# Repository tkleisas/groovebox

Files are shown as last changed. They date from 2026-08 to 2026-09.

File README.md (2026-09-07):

# groovebox — ВОКОИТЕР / ΟΡΓΑΝΟ

A standalone, battery-powered groovebox: a **Raspberry Pi Zero 2W** brain
running the [yawn](https://github.com/tkleisas/yawn) audio engine, with a
**Raspberry Pi Pico** panel module presenting the whole control surface to
the Pi as a plain USB-MIDI device. Screen, step-sequencer LEDs, encoders,
mic — everything else hangs off those two chips.

Design language: Soviet-cosmonaut mission control per
[bokontep.gr](https://www.bokontep.gr) — deep-red faceplate, cream/black
keys, bilingual Greek/Cyrillic UI strings, terminal-green telemetry.

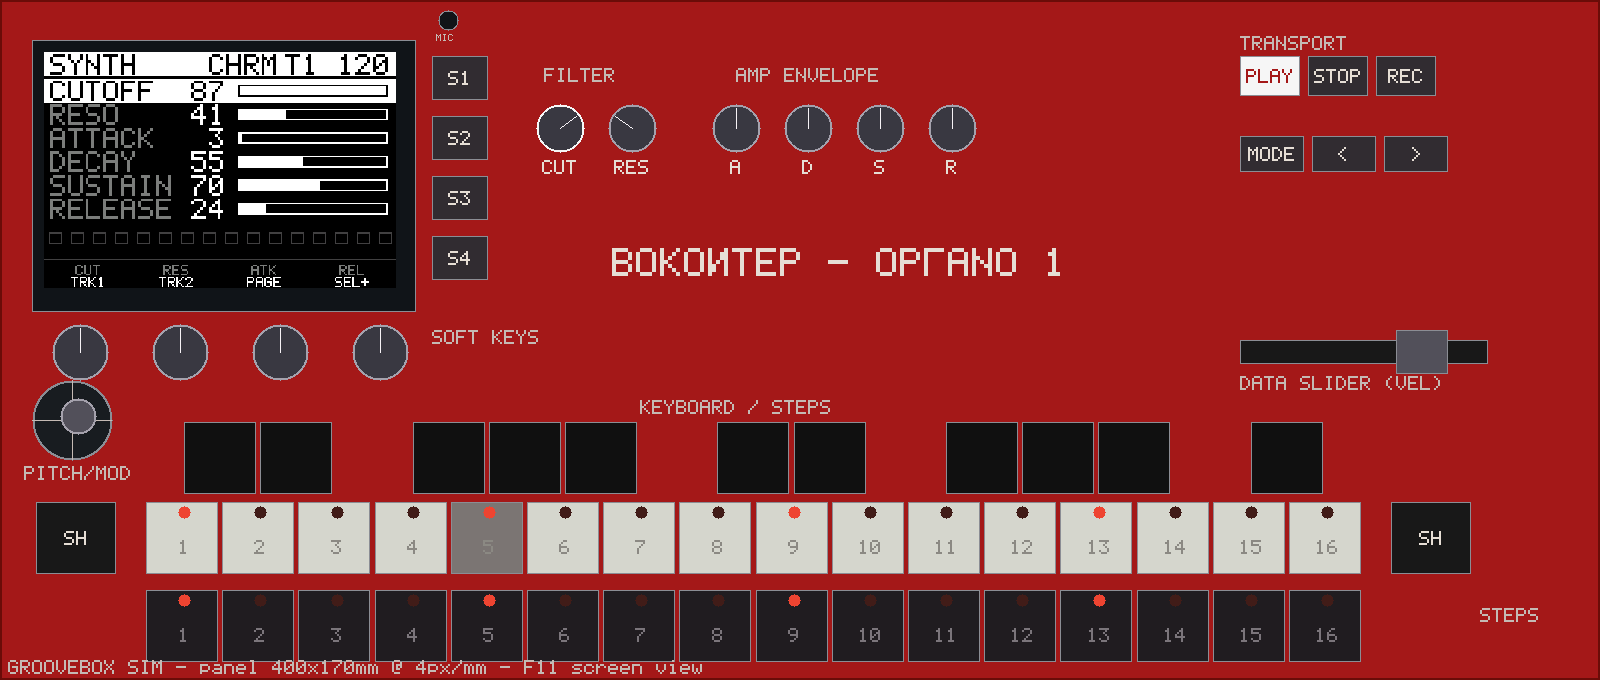
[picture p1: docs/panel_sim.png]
virtual front panel


## Two designs, one repo

| | NSR-1 (ΟΡΓΑΝΟ 1) | NSR-2 |
|---|---|---|
| Concept | full-size panel, 400 × 150 mm | compact, 180 × 210 mm faceplate PCB |
| Keys | 27 MX keys (piano row) + 12 function | 45 Choc keys (4×8 grid) + 13 function |
| Control | 4 encoders, 6 pots, data slider, thumbstick | 4 encoders, thumbstick, crossfader |
| Status | design + hardware spec rev A, KiCad skeletons | schematic-complete, **0 ERC errors**, footprints assigned |
| Docs | [`docs/design.md`](docs/design.md) | [`docs/nsr2-design.md`](docs/nsr2-design.md) + [`nsr2/README.md`](nsr2/README.md) |

## What it does (emulator, today)

- **4 tracks** × **1–256 step patterns** (default 16, 16-step paged window).
  Per-step: on/off, velocity (data slider), accent (black keys), pitch and
  gate (hold-step + encoders, synth track).
- **Play mode**: the keyboard row becomes a 2-octave chromatic keyboard,
  velocity from the slider, joystick = pitch bend / mod. REC-arm + play
  records quantized notes into the pattern. On **drum tracks**
  (DrumSynth/DrumRack/DrumSlop) the 27 keys instead walk the
  instrument's drum voices left→right (whites and interleaved blacks as
  one physical strip, position modulo voice count — wraps at the end,
  so every key always sounds); toasts show the voice name.
- **Sound**: yawn engine instruments (SubtractiveSynth, DrumRack, FM,
  Wavetable, Granular, …) + one insert FX slot per track (29 effect types).
- **Sampling**: SAMPLE page — record from mic/line-in, trim, normalize,
  assign to a drum pad; LOAD page browses samples.
- **Controls (NSR-1)**: 6 dedicated pots (filter cutoff/resonance + amp ADSR
  — strict one-parameter-one-control rule), 4 pageable encoders with push,
  data slider, 2-axis spring-return thumbstick, transport, MODE, </>,
  4 soft keys, dual SHIFT keys at the keyboard row ends.
- **UI**: Elektron-style monochrome, 3 themes (mono / red / green phosphor),
  ПОЕХАЛИ! boot splash, full widget library (sequencer, mixer, waveform,
  ADSR, FM-algo, spectrum, phase pie, tuner, file browser, virtual keyboard…).
- **Sync/IO**: DIN MIDI in/out, Ableton Link (engine), USB-MIDI on OTG,
  integrated mic + line in for sampling (WM8731 codec).

## Hardware (NSR-1, rev A)

| | |
|---|---|
| Brain | Raspberry Pi Zero 2W (≥5 h battery is a hard requirement) |
| Panel controller | Raspberry Pi Pico — presents as USB-MIDI device `groovebox-panel` |
| Audio codec | Audio Injector Zero (WM8731: stereo out + mic/line in). Bench rig: CJMCU-1334 (UDA1334A, playback only) |
| Display | 4.0" SPI TFT 480×320 (ILI9488); UI rendered at 240×160, 2× integer scale |
| Keys | 39 MX-style switches (Gateron Red / Silent Red), hot-swap sockets, per-key LEDs (whites), 19.05 mm pitch |
| Panel I/O | 3× MCP23017 (39 single-ended keys), HT16K33 (16 LEDs), 3× ADS1115 (6 pots + slider + joystick) |
| Power | LiPo + Adafruit PowerBoost 1000C |
| Panel size | 400×150 mm, deep red |

Full hardware design, GPIO maps and BOM: [docs/design.md](docs/design.md).
Panel/brain protocol (USB-MIDI + SysEx config):
[docs/panel-protocol.md](docs/panel-protocol.md).

## Architecture

```
  Pi Zero 2W (brain)                      Pico (panel module)
  ├ yawn engine (I2S codec)      ◄─USB─►  ├ keys    (3× MCP23017)
  ├ fbdev UI → 480×320 SPI TFT            ├ LEDs    (HT16K33)
  ├ DIN MIDI in/out (UART)                ├ encoders (GPIO)
  └ mic (codec input)                     └ analog  (3× ADS1115)
```

The panel is deliberately dumb — it reports physical events and accepts
routing SysEx; **all musical semantics live in the brain app**. The same
app binary runs on the PC (SDL3 emulator with a geometry-driven,
mouse-interactive virtual front panel) and on the Pi (fbdev + panel over
USB-MIDI) through a HAL, which is how everything is developed before
hardware exists. See [`docs/panel-protocol.md`](docs/panel-protocol.md)
for the wire protocol.

## Building

| Target | How | Needs |
|---|---|---|
| Emulator | CMake in `emulator/` (binary `groovebox_sim`) | MSVC or GCC, SDL3, yawn submodule (`git submodule update --init`) |
| Panel firmware | `panel-fw/build.ps1` or CMake with the Pico SDK (see `panel-fw/README.md`) | Pico SDK + toolchain |
| OS image | Raspberry Pi OS Lite + `os-image/customize/` (first-run script, systemd unit) | a Pi / imager |
| Hardware | KiCad 10; NSR-2 schematics are **generated** — see [`nsr2/README.md`](nsr2/README.md) before touching them | KiCad 10.0+ |

Windows/MSVC emulator build:

```bash
CMAKE="/c/Program Files/Microsoft Visual Studio/2022/Community/Common7/IDE/CommonExtensions/Microsoft/CMake/CMake/bin/cmake.exe"
"$CMAKE" -B emulator/build -S emulator -G "Visual Studio 17 2022" -A x64
"$CMAKE" --build emulator/build --target groovebox_sim --config Debug -- -m
emulator/build/Debug/groovebox_sim.exe            # interactive sim
```

The yawn engine is built lean (VST3 / NAM / Link / 3D / ONNX / video OFF).

### Pi cross-build (arm64, Docker)

`tools/build-pi-arm64.sh` builds `groovebox_sim` for 64-bit Raspberry Pi
OS (bookworm, aarch64) in a Docker container — no Pi needed on the desk:

```bash
tools/build-pi-arm64.sh     # image + cross-build + provenance + qemu smoke
```

The image (`emulator/pi/Dockerfile`) is Debian bookworm with the
`aarch64-linux-gnu` toolchain and the **arm64** `libasound2-dev` (ALSA is
the one target-arch dependency — RtMidi and PortAudio are compiled from
source by yawn's FetchContent but link against the target's ALSA). The
toolchain file is `emulator/pi/aarch64-toolchain.cmake`; CMake is driven
with `-DGB_PI_BACKEND=ON`, which swaps the SDL3 SimBackend for the
headless PiBackend (fbdev + RtMidi) and drops the SDL3 link. The script
finishes by proving the binary (`readelf -h` → `AArch64`) and
smoke-running it under `qemu-aarch64` (the container has no ALSA device
PortAudio accepts, so the engine can't boot there — the qemu run proves
execution + graceful peripheral degradation; `--profile` numbers need a
Pi with a codec or the Windows sim).

### Pi backend (PiBackend, `GB_PI_BACKEND=ON`)

- **Display**: fbdev — opens `/dev/fb1` (ILI9488 SPI TFT via fbtft
  overlay), falls back to `/dev/fb0`, mmaps the framebuffer and writes
  the 240×160 RGB565 UI frame 2×-doubled (480×320), centered. 16 bpp
  writes through; 32 bpp (XRGB8888) converts per pixel.
- **Panel in**: RtMidi input on the port named `groovebox-panel`,
  decoded per [`docs/panel-protocol.md`](docs/panel-protocol.md)
  (channel 1: notes 36–91 → keys, CC 20/21 pots, CC 26 slider, CC 1
  joystick Y, CC 16–23 encoder deltas, CC 32–39 encoder push,
  pitch bend → joystick X).
- **LEDs**: note on/off on channel 2 back to the panel.
- Neither peripheral is fatal — a Pi booted without the panel or the
  display logs a warning and keeps the engine running (CI / profiling).
- SIGINT/SIGTERM route to the app's quit path, so the systemd unit or
  Ctrl-C shuts the engine down cleanly.

Deployment note: the arm64 binary dynamically links `libportaudio.so.2`
(yawn builds PortAudio shared). Ship `emulator/build-pi-arm64/lib/libportaudio.so.2`
alongside the binary (e.g. in `/usr/local/lib` + `ldconfig`, or next to
the binary with an rpath). `libasound.so.2` is part of Raspberry Pi OS.

### Heavy-load profiling (`--profile`)

```
groovebox_sim --profile 10
```

Worst-case musical load for the Zero 2W gate: all 4 tracks programmed on
all 16 steps (vel 120), 140 BPM, a reverb inserted on T1+T2, transport
rolling, UI rendering every frame. Prints PortAudio CPU% and the
PortAudio callback status flags (xrun bits) once per second, then exits
0. Runs on every backend (Windows sim, Pi hardware, qemu).

### Interactive controls (sim)

- **Mouse** (panel view): click keys/buttons; drag pots & slider; 2D-drag
  joystick (springs back); wheel over encoders; click encoder = push.
- **PC keyboard**: Z-row + Q-row = piano whites (with standard black-key
  letters/digits), Space = play/stop, Enter = rec, Tab = MODE,
  arrows = </>, F1–F4 = soft keys S1–S4, Shift = SHIFT, F5–F10 + `-`/`=` =
  pots, `[`/`]` = slider, F11 = panel/screen view, F12 = theme, ESC = quit.
- **Track select**: S3/S4 (TRK-/TRK+) or Shift + white keys 1–4;
  Shift + white 5–8 = mute.

### Drum editing (INST page on drum tracks)

For pad instruments (DrumSynth / DrumRack / DrumSlop) the INST page
edits the **last-played pad**: hitting a key in play mode (or a
hold-step voice p-lock) makes that voice the edit pad — the header
shows it (`SNARE T1 140`), an `EDIT SNARE` toast confirms, and all
bindings rebuild to that voice. Sequencer playback never steals the
edit focus.

- **Encoder pages**: PAD / PAD2 = the edited pad's params (DrumSynth:
  Tune/Drive, kick adds Sine/White/Pink; DrumRack: Pad Vol/Pan/Pitch/
  Choke/Start/End; DrumSlop: Pad Vol/Pan/Pitch/Rev/Cutoff/Reso),
  KIT = instrument globals (Volume, OS 2×, slice controls). S2 = PG+
  cycles them.
- **Macro encoders 5–8** (factory binding): A/D = the edited pad's
  attack/decay (S/R also bound on DrumSlop). Pots stay inert on
  DrumSynth/DrumRack (CUT/RES bind only where the instrument exposes
  them — DrumSlop pads).
- DrumSynth has no selected-slot concept — its 36 params are globally
  indexed per voice (kick = 7 @ index 0, others = 4 @ 7+(slot−1)·4),
  so the edit pad is pure index arithmetic; DrumRack/DrumSlop get the
  pad via their `selectedPad` setter.

### Scripted test / asset modes

```
groovebox_sim --smoke       engine boot + notes self-test
groovebox_sim --uitest      UI interaction assertions (8/8)
groovebox_sim --seqtest     sequencer scheduling assertions (6/6)
groovebox_sim --longtest    1–256 step pattern assertions (9/9)
groovebox_sim --paramtest   pot pickup / encoder ownership / FX (11/11)
groovebox_sim --sampletest  mic capture → trim → assign → browser (8/8)
groovebox_sim --panelprobe  synthetic mouse → HAL events (3/3)
groovebox_sim --panel=nsr2 --nsr2test    NSR-2 grid semantics (6/6)
groovebox_sim --revbtest    NSR-1 rev B: step row, p-lock, scale lock (6/6)
groovebox_sim --macrotest   macro encoder assign/bind/reset/persist (6/6)
groovebox_sim --tracktest   engine tracks, INST swap, MFX, type toggle (4/4)
groovebox_sim --bouncetest  clip record, bounce, FX slot 2 (7/7)
groovebox_sim --drumtest    drum key map: voices, wrap, p-lock (9/9)
groovebox_sim --padtest     last-played-pad edit focus (8/8)
groovebox_sim --panel=nsr2 --panelprobe  synthetic mouse on NSR-2 (3/3)
groovebox_sim --widgets     widget showcase → docs/widgets.png
groovebox_sim --profile 10  heavy-load profiling: CPU% + xrun flags/s
groovebox_sim --fontchart   font chart → docs/fontchart.png
groovebox_sim --themes      3-theme chart → docs/themes.png
groovebox_sim --paneldump   panel render → docs/panel_sim.png
groovebox_sim --splashdump  boot splash → docs/bootsplash.png
```

`--panel=<nsr1|nsr2>` selects the panel profile (faceplate, key
semantics, LED count) for interactive, test, and dump modes
(`--panel=nsr2 --paneldump panel.png` renders the NSR-2 faceplate).

## Repository layout

| Path | What it is |
|---|---|
| `docs/` | design documents: NSR-1 `design.md`, panel ↔ brain protocol (`panel-protocol.md`), NSR-2 `nsr2-design.md`, mockups & generated charts |
| `emulator/` | the groovebox app + device emulator (`hal.h`, SimBackend = SDL3 desktop, PiBackend = headless Pi fbdev+RtMidi, PanelView, ui, widgets, font5x7, pattern…), `pi/` = arm64 cross-build (Dockerfile + toolchain) |
| `panel-fw/` | Raspberry Pi Pico firmware (TinyUSB USB-MIDI panel controller, protocol v1 + GRV SysEx config) |
| `hardware/` | NSR-1 hardware: netlist spec + KiCad projects (keyboard & control boards) |
| `nsr2/` | the NSR-2 compact variant: netlist spec, generated KiCad schematics, footprint library, enclosure spec, mockup |
| `os-image/` | Raspberry Pi OS Lite customization — boots straight into the app (~10 s to sound) |
| `tools/` | mockup generators (panel, UI), rgb565 conversion |
| `yawn/` | the audio engine (git submodule) |

## Status & roadmap

NSR-2 is the active design: schematics generated and ERC-clean, board
outlines drawn (180 × 210 faceplate with screen window, 100 × 80 brain
carrier), 3D-printed enclosure specified. Next: PCB layout, firmware
`PANEL_NSR2` variant, emulator `--panel=nsr2` profile. NSR-1 remains the
reference for the audio engine bring-up and the panel protocol.

Software milestones (emulator-first):

- **M1 done** — emulator skeleton: engine headless on PC, HAL, sim window,
  font (Latin/Greek/Cyrillic + symbols), 26 widgets.
- **M2 done** — full instrument in the emulator: live step sequencer
  (1–256 steps), play mode, per-step pitch/gate, virtual front panel,
  themes, boot splash, pot pickup, encoder parameter pages, FX page,
  SAMPLE/LOAD/SETTINGS pages, dialogs. M2d adds one engine track per UI
  track (engine-level mutes, per-track FX), INST page (instrument
  picker with full param rebind), MFX page (MIDI-effect slot), TRACK
  page (channel type MIDI/AUDIO + vol/pan/input/monitor), macro
  encoders (assignable, persisted). AUDIO tracks record input into
  looping clips (REC arm + PLAY/STOP); BOUNCE renders a MIDI track's
  pattern offline to a WAV + looping clip on the first AUDIO track.
  FX page has two insert slots per track (shift+S2 switches).
- **M3 done** — Pi software path: headless PiBackend (fbdev 2× display +
  RtMidi panel per `docs/panel-protocol.md`) behind `-DGB_PI_BACKEND=ON`,
  Docker arm64 cross-build (`tools/build-pi-arm64.sh`, ELF64 AArch64
  verified), `--profile N` heavy-load harness (4 tracks dense, 140 BPM,
  reverb ×2, per-second CPU% + xrun flags).
- **M4** — bench rig: codec, panel firmware on real hardware, display.
- **M5** — battery, enclosure, custom PCB if it earns one.

## Conventions

- Commit messages: `area: summary` (`panel-fw:`, `os-image:`, `nsr2:`, `docs:`).
- Generated files are marked as such in their directories — read
  [`nsr2/README.md`](nsr2/README.md) before hand-editing anything in
  `nsr2/hardware/`.
- Per-device credentials never enter the repo (see `os-image/customize/`).
- License: MIT (see [`LICENSE`](LICENSE)). Vendored third-party hardware
  libraries keep their own licenses — see the footprints table in
  [`nsr2/README.md`](nsr2/README.md).

ПОЕХАЛИ!

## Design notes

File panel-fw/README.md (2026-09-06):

# groovebox-panel firmware

Panel module firmware for the groovebox control surface: a Raspberry Pi Pico
scanning 55 single-ended keys plus 8 encoder pushes on 4x MCP23017 expanders,
2x ADS1115 analog inputs (CUT/RES pots, slider, joystick X/Y), 8 encoders
(5-8 = ADSR) and 32 LEDs driven by an HT16K33 (LED driver only,
no key matrix), presenting everything as a stock USB-MIDI device named
`groovebox-panel` — protocol v1 per [docs/panel-protocol.md](../docs/panel-protocol.md)
(keys as Note On/Off ch1, pots/slider/joystick as CC, encoders relative CC,
LEDs and the host velocity register on ch2, GRV SysEx 0x7D configuration).

## Layout

    CMakeLists.txt          build definition (pico-sdk 1.5.x)
    build.ps1               Windows build helper
    src/board_config.h      pins, I2C addresses, expander key maps — PCB-facing constants
    src/main.c              superloop + 1 ms tick
    src/usb_descriptors.c   "groovebox-panel" MIDI device (VID 0x2E8A, PID 0x4720)
    src/midi.c/.h           TX helpers + RX parser (ch2 notes/CC27/SysEx)
    src/keys.c/.h           55 keys + 8 encoder pushes on 4x MCP23017, debounced scan
    src/ads1115.c/.h        2 chips round-robin, ~125 Hz/channel, hysteresis
    src/encoder.c/.h        8x quadrature IRQ (pushes ride the key scan)
    src/leds.c/.h           32-LED RAM mapping (HT16K33 LED driver) + re-assert
    src/config.c/.h         velocity source routing, GRV SysEx, flash persistence

## Building (Windows)

One-time setup (no admin needed, everything user-scoped under
%USERPROFILE%\pico-tools):

    # 1. pico-sdk 1.5.1 with submodules (last 1.x release; there is no 1.5.2 tag)
    git clone --depth 1 --branch 1.5.1 --recurse-submodules `
        --shallow-submodules https://github.com/raspberrypi/pico-sdk `
        "$env:USERPROFILE\pico-tools\pico-sdk"

    # 2. Arm GNU toolchain 13.2.Rel1 (mingw-w64-i686 zip)
    #    -> extract into %USERPROFILE%\pico-tools
    # 3. ninja-win.zip -> extract into %USERPROFILE%\pico-tools\ninja

Then:

    .\build.ps1 -Configure   # first run
    .\build.ps1              # incremental -> build\panel.uf2

Linux/macOS: standard pico-sdk flow — `cmake -B build -G Ninja` with
arm-none-eabi-gcc on PATH; no Python needed (no PIO/WL features used).

## Flashing

Hold BOOTSEL, plug the Pico, drag `build\panel.uf2` onto the RPI-RP2 drive.
SWD (Pico H 3-pin) works too.

## Testing without the Pi

The panel is a plain class-compliant USB-MIDI device: plug it into any PC and
watch events in a MIDI monitor (amidi / MIDI-OX / web MIDI). Key presses emit
Note On ch1 (36 + key index, velocity from the active source); pots emit
CC20/21 (CUT/RES), the slider CC26, joystick CC1/bend; encoders CC16..23
relative (5-8 = ADSR) and CC32..39 push. Drive LEDs: Note On/Off ch2, note
0..31 (0..15 step row, 16..31 white keys). Configuration SysEx:

    set velocity source = fixed 100   F0 7D 47 52 56 01 08 64 F7
    query capabilities                F0 7D 47 52 56 02 F7
    persistence on                    F0 7D 47 52 56 04 01 F7
    factory reset                     F0 7D 47 52 56 7F F7

## Bring-up knobs (hardware-verification points)

- HT16K33 init sequence in `leds.c` (oscillator on 0x21, brightness 0xE0|8,
  display on 0x81): the chip boots in standby — if no LED lights on first
  boot, verify these writes land with an I2C monitor.
- LED RAM mapping in `leds.c` (LED i -> RAM[i & 7] bit (i >> 3)) must match
  the keyboard PCB routing (ROW anode / COM cathode pairing).
- `KEY_CHIPS` maps (board_config.h): MCP23017 pin -> panel key index; route
  the keyboard PCB to match these tables (or update the tables).
- Encoders: if one detent advances two steps per click, flip the qdec table
  orientation in `encoder.c`.

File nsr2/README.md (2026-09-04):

# NSR-2 — Directory Guide & Collaboration Contract

NSR-2 is the compact sibling of NSR-1 (this repo's `docs/design.md` rev A).
Design docs: `docs/nsr2-design.md`, `nsr2/netlist-spec.md`,
`nsr2/enclosure-spec.md`.

## What generates what

| File | Status | Produced by |
|---|---|---|
| `netlist-spec.md` | **SOURCE OF TRUTH** for all circuits | hand-edited (both of us) |
| `tools/gen_schematics.py` | generator | hand-edited (both of us) |
| `hardware/brain/brain.kicad_sch` | **GENERATED — do not hand-edit** | `gen_schematics.py` |
| `hardware/io/io.kicad_sch` | **GENERATED — do not hand-edit** | `gen_schematics.py` |
| `hardware/nsr2.kicad_sym` | **GENERATED — do not hand-edit** (custom HT16K33A symbol) | `gen_schematics.py` |
| `mockup_panel.py` → `panel_mockup_nsr2.png` | generator + output | hand-edited |
| `hardware/*/*.kicad_pcb` | board outlines machine-made; **layout becomes HAND-OWNED the moment layout work starts in KiCad** | — |
| `hardware/*.kicad_prl`, `erc*.json`, `*_sch.pdf/png`, `*_outline.*`, `io_net.net` | disposable artifacts | KiCad / scripts |

## The collaboration contract

1. **The chain of truth is: `netlist-spec.md` → `gen_schematics.py` →
   `.kicad_sch`.** Any circuit change goes: update the spec → update the
   generator → regenerate → re-verify (ERC + netlist + render) → review.
2. **Never hand-edit the generated `.kicad_sch` files** (or
   `nsr2.kicad_sym`) while this contract is active — regeneration wipes
   hand edits. Spot something wrong? Report it; it gets fixed in the
   generator so the fix survives.
3. **The KiCad GUI is for review and measurement only** during this
   phase (ERC, net highlighter, reading values). Saving a session is
   fine — it only writes view settings (`.kicad_prl`).
4. **Freeze procedure**: when the schematic review passes, we record the
   freeze here (date + commit), after which the `.kicad_sch` files are
   handed over — hand edits in KiCad become the norm, the generator is
   retired for schematics (kept for reference). The `.kicad_pcb` layout
   is hand-owned regardless, from the first moved footprint.
5. Regenerate + verify before every commit that touches hardware.

## Regenerate & verify

```
python nsr2/tools/gen_schematics.py
kicad-cli sch erc  nsr2/hardware/brain/brain.kicad_sch --output out --format json --severity-all
kicad-cli sch erc  nsr2/hardware/io/io.kicad_sch    --output out --format json --severity-all
kicad-cli sch export netlist --format kicadsexpr nsr2/hardware/io/io.kicad_sch --output io_net.net
```

## Known ERC warnings (expected — do not "fix" blindly)

As of the 2026-08-31 generation (with footprints assigned), with
`--severity-all`:

| Board | Count | Class | Meaning |
|---|---|---|---|
| brain | 37 | `lib_symbol_mismatch` | my generated copies differ cosmetically from the installed library defs. **Zero effect** on connectivity, netlist or PCB. Clearable later via *Update Symbols from Libraries*. |
| brain | 1 | `isolated_pin_label` | `MIC_SIG` — intentional: the mic capsule's far end is the codec's physical jack. |
| io | 107 | `lib_symbol_mismatch` | same as above |

**Red flags — these must NEVER appear.** If any of these show up in ERC,
a generation regression happened; stop and diff the generator:

`power_pin_not_driven`, `pin_to_pin`, `label_dangling`,
`pin_not_connected`, `endpoint_off_grid`, `multiple_net_names`,
`footprint_link_issues`.

(Historical note: all of these were real bugs during generation and were
fixed — see `tools/bisect_sch.py` and `tools/exp_power.py`, kept as
regression probes.)

## Footprints

All schematic symbols now carry footprints. The project library
`nsr2_footprints.pretty` (registered in both projects' `fp-lib-table` as
`nsr2_fp`) holds the three that standard KiCad lacks:

| Footprint | Provenance |
|---|---|
| `SW_Hotswap_Kailh_Choc_V1` | [kiswitch library](https://github.com/kiswitch/keyswitch-kicad-library) (CC-BY-4.0), converted to current format |
| `DIN5-RA-PTH` | SparkFun-Connectors.pretty (vendored copy), converted |
| `SW_SPDT_SLIDE_THT` | generated (generic EG1218-class SPDT slide — verify against the bought part) |

Also note: the Pi and Pico sit on **female** headers — their 2×20
symbols use `PinSocket_2x20_P2.54mm_Vertical`, and the screen header is
`PinHeader_1x08_P2.54mm_Horizontal` (right-angle).

## KiCad quick notes for this project

- The schematics use **named labels instead of wires**: every `KEY17`
  label is the same electrical node. Use the net-highlighter (target
  icon, right toolbar) and click a label to see its whole net.
- ERC: *Inspect → Electrical Rules Checker*.
- The custom HT16K33A symbol is embedded, so it displays without extra
  setup; `sym-lib-table` makes the `nsr2` library resolvable for ERC.
- Both boards: io = 180×210 faceplate (screen window at 40,8–140,80),
  brain = 100×80. Outlines are already on Edge.Cuts.

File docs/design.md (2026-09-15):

# Groovebox — Hardware & Software Design

A standalone, battery-powered groovebox built on Raspberry Pi Zero 2W,
using the [yawn](https://github.com/tkleisas/yawn) audio engine as the DSP core.

**Identity: ВОКОИТЕР – ΟΡΓΑΝΟ 1.** Deep-red faceplate (Nord/Elektron red
family), white/black MX keys, near-black shift keys, off-white panel print;
brand badge center-panel in the UI's own multilingual 5×7 font.

Aesthetic direction (per bokontep.gr): Soviet-cosmonaut mission control —
boot splash "ПОЕХАЛИ!", mission-register terminology (project = ΑΠΟΣΤΟΛΗ),
bilingual Greek/Cyrillic UI strings, telemetry-style status pages.
Three screen themes: MONO (white/gray on near-black), RED (bright/light red —
matches the faceplate), GREEN (bright/light green phosphor).

## Core decision

**Pi Zero 2W, fixed by a hard requirement: ≥5 h battery life.**

Considered alternatives:
- Pi 4B: ~3–4× CPU headroom and up to 8 GB RAM, but 3–5 W draw cuts
  battery life to ~2–3 h and it wants a heatsink. Rejected on the battery
  requirement alone.
- CM4: right answer only for a custom carrier PCB / production run.
  Revisit if the box ever goes beyond a one-off.
- Pi 5: power draw and active cooling make it wrong for portable use.

Consequences:
- The core is a swappable module — everything hangs off the standard 40-pin
  header, so a Pi 4B could drop in later with only battery/heatsink changes.
- Milestone 1 must include profiling on the Zero 2W: target workload =
  4 tracks (drum rack + synth + 2–3 FX per track) at 128 frames / 48 kHz.
  Ship criterion: sustained CPU ≤ ~60–65% with no xruns. If it fails, the
  fallback is reducing scope (fewer tracks / lighter FX), not switching
  cores, since battery life is the hard constraint.
- **Measured on real hardware (v0.0.5, snd-dummy, 256 frames, Release):
  lean 4×4-step 120 BPM = 36–43% clean; dense 4×8-step 120 BPM + 1 reverb
  = 55–66% clean; worst-case 16-step 140 BPM + 2 reverbs = ~101% xruns.**
  Verdict: PASSES for the intended envelope. Practical rule: one reverb at
  a time on this core; cheap FX are fine. Re-confirm on the real codec at
  128 frames during bench bring-up (M4).

## Concept

- Mixed sample + synth instrument: yawn's session grid, instruments
  (Sampler, Drum Rack, Subtractive, FM, Wavetable, ...) and effects,
  driven by a physical control surface.
- 4 tracks to start (session-style clip launching), piano-style 16-key step
  row, dedicated filter/ADSR pots, one data slider (default: velocity).
- **Patterns: 1–256 steps, global length, default 16**, grid shows a 16-step
  window (follow-playhead + manual paging via shift+</>). No formal time
  signature — length in steps IS the meter (12 = 3/4, 14 = 7/8); the clock
  counts 16-step bars. Per-step: on/off, velocity (slider at entry),
  accent (black keys), pitch + gate (hold-step + encoders, synth track).
- No desktop OS involvement: Raspberry Pi OS Lite, systemd unit boots
  straight into the app (~10 s boot-to-sound).

## Bill of materials (~$70–80)

| Part | Choice | ~Cost |
|---|---|---|
| Brain | Raspberry Pi Zero 2W | $15 |
| Panel controller | Raspberry Pi Pico (RP2040) — USB-MIDI bridge for all panel I/O | $5 |
| Audio codec (final) | Audio Injector Zero (WM8731: stereo out + mic/line in, stacks on header) | $18 |
| Audio out (bench rig) | CJMCU-1334 = **UDA1334A** I2S DAC, already on hand + proven wiring (`hifiberry-dac` overlay). Playback only — no ADC | $0 |
| Mic | Electret capsule behind top-panel hole → codec mic input | $2 |
| Display | 4.0" SPI TFT 480×320 (ILI9488) — bigger pixels for eyesight; same driver, bus and 240×160@2× UI as 3.5" | $18 |
| MX keyboard kit | 55 MX-style switches (Gateron Red / Silent Red, linear ~45 gf) + Kailh hot-swap sockets + keycap set (16 white, 11 black, 16 step row, colored function keys) | $65 |
| Button/LED driver | HT16K33 (I2C, drives 32 LEDs: 16 step row + 16 white keys) | $3 |
| Key input expanders | 4× MCP23017 (I2C @ 0x20–0x23, 55 single-ended key inputs) | $8 |
| Analog inputs | 3× ADS1115 16-bit ADC (I2C, addresses 0x48 / 0x49 / 0x4a) | $9 |
| Pitch/mod | 2-axis spring-return thumbstick (X = pitch bend, Y = mod) | $4 |
| Pots | 6× 10k linear: cutoff, resonance, A, D, S, R | $7 |
| Data slider | 60 mm slide pot (velocity default; live filter/FX sweeps) | $3 |
| Encoders | 4× rotary encoder with push | $5 |
| DIN MIDI | 2× 5-pin DIN sockets (in+out), 6N138 optocoupler, resistors | $5 |
| Power | LiPo 2000–3000 mAh + Adafruit PowerBoost 1000C | $20 |
| Misc | Power switch, perfboard, headers, enclosure | $5 |

## Control surface

- **Dedicated step row (rev B)**: 16 MX switches *under* the keyboard, one
  per step of the current 16-step window, each with an LED. The step row is
  always the sequencer; the piano row is always playable — no mode split.
  Gestures: tap step = toggle; **hold step + tap piano key = set that
  step's pitch** (p-lock); hold step + encoder = gate; shift+step = accent;
  shift+step on tracks 1–4 area = track select/mute.
- Piano row: 16 white + 11 offset black keys in piano pattern,
  **MX-style switches at 19.05 mm pitch** (Gateron Red / Silent Red, linear
  ~45 gf) in **hot-swap sockets**, per-key LEDs (whites show held notes /
  scale guides), always playable — 2-octave chromatic from C4, velocity
  from the slider. MODE toggles keyboard scale-lock (chromatic ↔ scale).
  External keybeds via DIN MIDI in (USB-MIDI on OTG also possible).
- Transport: play, stop, rec.
- **Two SHIFT keys** (1u MX keys), same logical modifier, at the two ends of
  the keyboard row — thumb/pinky pins shift while the other fingers hit the
  target, so every shift combo is a one-hand move:
  - shift + step row → accent / track select / mute
  - shift + encoder → fine adjust / reset to default
- **MODE** key: toggles keyboard scale-lock (chromatic ↔ scale-locked);
  the sequencer and keyboard are always both live — no mode split.
- **< / >** keys: previous/next event, page, or preset.
- **4 soft menu keys** under the screen: functions shown as on-screen
  labels directly above each key (MPC-style menus, no legend needed).
- 4 encoders with push (pageable parameters).
- **8 encoders total (rev B2)**: 4 pageable + 4 dedicated amp-ENV
  A/D/S/R (relative control — no pickup; envelope follows the track).
  Encoder push-buttons live on spare MCP23017 inputs (quadrature stays on
  16 direct GPIO).
- 2 pots: filter cutoff + resonance (absolute performance controls).
- 1 data slider (velocity entry; mappable).
- 2-axis spring-return thumbstick left of the keyboard: X = pitch bend
  (centers on release), Y = mod, assignable (vibrato / filter / FX depth).
- LEDs mirror pattern + playhead even when the screen shows another page.

Front-panel layout: `docs/panel_mockup.png` (to scale, **400×170 mm panel** —
desktop-instrument class, Push 2 width; regenerate with
`python tools/mockup_panel.py`). Screen-centric design: screen top-left with
the 4 soft menu keys in a column beside it (menu labels drawn on screen next
to each key) and the 4 encoders in a row directly beneath it (parameter
labels + values on screen above each encoder). CUT/RES/A/D/S/R pots
top-middle, transport + MODE/</> cluster top-right, pitch/mod thumbstick
bottom-left, full-width MX piano keyboard (16 white @ 19.05 mm + 11 offset
black, always playable) above a **dedicated 16-key step row** (always the
sequencer, per-step LEDs), 1u SHIFT keys at the piano row ends, horizontal
60 mm data slider above the keyboard's right end. The center holds the
ВОКОИТЕР – ΟΡΓΑΝΟ 1 badge.

## GPIO / I2C allocation

**Pi Zero 2W (40-pin header)** — Pi keeps only display, codec, and DIN MIDI:

| Bus | Pins | Device |
|---|---|---|
| I2S | GPIO 18 (BCK), 19 (LRCK), 21 (DOUT), 20 (DIN) | WM8731 codec (Audio Injector Zero: playback + mic capture) |
| SPI0 | GPIO 8 (CE0), 10 (MOSI), 11 (SCLK) + DC/RST/BL on GPIO 24/25/27 | ILI9488 display |
| I2C1 | GPIO 2 (SDA), 3 (SCL) | WM8731 ctrl @ 0x1a |
| UART | GPIO 14 (TXD), 15 (RXD) | **DIN MIDI out / in** (31250 baud) |
| USB OTG | micro-USB "USB" port | **Panel module (Pico, USB-MIDI device)** |

**Pico (panel module)** — everything else moves here:

| Peripheral | Connection | Role |
|---|---|---|
| HT16K33 | I2C @ 0x70 | 32 LEDs: 16 step-row + 16 white-key (driver only) |
| 4× MCP23017 | I2C @ 0x20 / 0x21 / 0x22 / 0x23 | 55 keys + 8 encoder push-buttons, single-ended (64 available: 63 used) |
| 2× ADS1115 | I2C @ 0x48 / 0x49 | 5 analog inputs: 2 pots (CUT/RES) + slider + joystick (X/Y) |
| 8 encoders | direct GPIO (16 pins, quadrature A/B only) | encoders 1–4 pageable, 5–8 = ADSR |

Notes:
- All 55 keys (16 white + 11 black piano + **16 step row (rev B)** +
  3 transport + 4 soft + MODE + < + > + 2 SHIFT) are **single-ended inputs
  on four MCP23017 I²C expanders** — one uniform scan path, no matrix and
  no per-key diodes (rev A deviation from the original HT16K33-matrix plan:
  the function keys are physically distributed across the panel, and
  expanders keep the board-to-board link at 4 wires with every key
  identical in hardware and firmware). The HT16K33 is solely an LED driver:
  16 step-row LEDs + 16 white-key LEDs.
- Integrated mic: electret capsule wired to the WM8731 mic input (codec bias
  + PGA gain via ALSA mixer). Uses the codec's capture path, no extra bus or
  pins. The WM8731 runs in master mode off an onboard crystal since the Pi's
  I2S has no MCLK output; the stock `audioinjector-wm8731-audio` overlay
  drives it (probes WM8731 at I2C 0x1a).
- Prototyping uses the on-hand CJMCU-1334 (**UDA1334A**, playback-only DAC,
  `hifiberry-dac` overlay — the same recipe as the 2019 intsynth card).
  The mic path arrives with the Audio Injector Zero; UDA1334A + separate
  I2S mic was rejected (custom overlay work, two boards instead of one).
- **DIN MIDI in/out is a core feature.** MIDI out is a TX pin + resistor
  network; MIDI in needs the 6N138 optocoupler (never feed a bare UART).
- On the Zero 2W the PL011 UART is claimed by Bluetooth by default — remap
  it back to GPIO 14/15 via the `pi3-disable-bt` (or `miniuart-bt`) device
  tree overlay, and disable the serial console.
- Software: `ttymidi` bridges `/dev/ttyAMA0` into the ALSA sequencer, so
  yawn's existing RtMidi stack sees DIN MIDI as just another MIDI port —
  clock sync in/out, note in, and MIDI Learn all come along for free.

## Software architecture

**Device emulator first.** All groovebox software is developed against a
hardware abstraction layer (HAL) so the same app binary runs on the PC
(sim backend: SDL3 window showing the exact 240×160 framebuffer at 2×,
keyboard/mouse standing in for keys/encoders/pots) and on the Pi
(fbdev SPI display + **panel module over USB-MIDI**). The PC emulator links the
real yawn engine natively (PortAudio/WASAPI) — UI, page flow, controller
mapping and sequencer logic are all proven before hardware exists.
Milestones: M1 emulator skeleton + headless yawn on PC → M2 full UI +
controller mapping in emulator → M3 cross-compile to Pi, Pi HAL backend,
CPU profiling (Zero 2W viability gate) → M4 bench rig → M5 battery +
enclosure.

**Panel module (Raspberry Pi Pico).** All panel I/O — 39 single-ended keys
on 3× MCP23017, 16 in-switch LEDs on HT16K33 (driver only), 4 encoders,
3× ADS1115 analog — is handled by a Pico (RP2040, native USB device via
TinyUSB) which presents itself to the Pi as a **USB-MIDI controller**. Keys
→ note on/off, pots/slider/joystick → CCs, encoders → relative CCs; LEDs
are driven by MIDI back to the panel; a SysEx layer (protocol doc)
configures velocity-source routing with capability handshake and optional
flash persistence. The Pico is I2C bus master for all expanders (its 26
GPIO can't absorb keys + LEDs + encoders directly). Benefits: no custom
I/O drivers on the Pi (yawn's RtMidi sees a stock USB-MIDI device),
jitter-free scanning, and a panel that is independently testable on any
MIDI host (PC/DAW) and swappable as a unit. The Pi's USB-OTG port goes to
the panel; external keyboards use DIN MIDI in. Firmware: `panel-fw/`
(builds to `panel.uf2` via pico-sdk; see `panel-fw/README.md`).

```
┌─ Input thread (libgpiod: encoders | HT16K33: buttons | ADS1115×2: pots/slider)
│        │  translates to CC / note / shift-layer events
│        ▼
│  "GROOVEBOX" controller backend ──► yawn engine
│        │  (PortAudio/ALSA, 64–128 frame buffer @ 48 kHz,
│        │   existing instruments / FX / session grid,
│        │   Lua 5.4 controller script)
│        ▼  state out: params, playhead, meters, LED state
├─ LED update (HT16K33)
└─ fbdev UI thread → ILI9488, ~15–20 fps, partial redraws
   (C++ + stb_truetype; no GPU — see constraints below)
```

Constraints / decisions:
- yawn's fw2 UI (SDL3 + OpenGL 3.3) cannot run on the Zero 2W
  (VideoCore IV = GL 2.1 / GLES 2.0 at best — fw2's shaders won't compile,
  regardless of the scanout path). The groovebox UI is a new, minimal
  software renderer writing to the Linux framebuffer (fbdev/`fb_ili9488`).
  GPU rendering (GLES2 → FBO → glReadPixels → SPI copy) remains an option
  for future shader-based visualizers (oscilloscope/spectrum), not for
  the core UI.
- **UI style: Elektron-inspired, blocky, near-monochrome** (mockup:
  `docs/ui_mockup.png`, regenerate with `python tools/mockup_ui.py`).
  Rendered at an effective 240×160 and integer-doubled to the display's
  native 480×320 during the SPI blit — 4× less raster work, large glyphs.
  Design language: inverted header bar (page title + context), parameter
  rows (dim name / bright value / thin bar), inverse-video selection
  cursor, footer strip showing the 4 encoders' current assignments,
  white/gray on near-black with at most one accent color (rec-arm,
  playhead, clip state). Partial-row updates to save SPI bandwidth.
- **Widget library** (`emulator/src/widgets.h`, 26 widgets): PhasePie,
  Waveform, Slice, ADSR, FM-algo, Spectrum, Sequencer, StepLane, Mixer,
  Wavetable, Knob, Switch, Radio, VirtualKeyboard, EditBox, FileBrowser,
  List, Toast, TransportClock, NumericField, Dialog, Battery, StatusIcons,
  Tuner, PadGrid, TabBar — all monochrome and data-driven.
  **Grid rule: every widget bbox is a multiple of 8 px (placement prefers
  16 px)** — 240×160 = 30×20 cells; widgets tile without pixel negotiation.
  Showcase: `docs/widgets.png` (regenerate with `groovebox_sim --widgets`).
- 512 MB RAM: ONNX / Demucs / Neural-Amp / video features stay OFF for this
  target (existing CMake feature flags).
- Rootfs mostly read-only + a shutdown button so battery pulls can't
  corrupt the SD card.

## Milestones

1. **Engine on the Pi** — headless yawn build (heavy features off), driven by
   a Lua script, audio out via PCM5102A. De-risks everything; pure software.
2. **Bench rig** — breadboard: encoders, a few buttons, display;
   input → controller backend → engine loop working.
3. **fbdev UI** on the 480×320.
4. **Full control surface** — HT16K33 buttons/LEDs, ADS1115 pots/slider.
5. **Battery + enclosure**, custom PCB if more than one unit is wanted.

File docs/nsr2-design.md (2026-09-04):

# NSR-2 — Compact Panel Variant

NSR-2 is the compact sibling of NSR-1 (this repo's `design.md` rev A).
Same architecture: Pi Zero 2W brain + Pico panel module as a USB-MIDI
device, yawn engine, same panel↔brain protocol v1. The panel is rebuilt
around a 4×8 Choc grid instead of the MX piano row; the pots are dropped
(the 4 encoders cover parameter editing). **Software is nearly
identical**: same app binary, same firmware skeleton, one build-flag
panel variant per hardware.

## Locked decisions

- **Switches**: Kailh Choc low-profile, ~14 mm pitch, hot-swap. MX
  requirement dropped.
- **Grid LEDs**: all 32 keys lit (HT16K33), pattern + playhead mirror as
  in NSR-1.
- **Pitch/mod thumbstick**: stays, on ADS1115 as in NSR-1.
- **Crossfader**: stays (the NSR-1 data slider, repurposed/mix duty).
- **Pots**: CUT/RES/A/D/S/R dropped — 4 pageable encoders take over.
- **Spacebar**: the space key of the quasi-keyboard — the 4×8 grid
  doubles as a text-entry keyboard (project/pattern naming); the wide
  bar types space. Semantics live in the brain (EditBox widget).
  Built as one Choc switch under a wide ~3u (~42 mm) low-profile cap.
- **Layout, top to bottom**: mic hole → screen → 4 soft keys (equally
  spaced under screen) → 4 encoders → transport + < / > on one line →
  4×8 grid → SHIFT-L, spacebar, SHIFT-R.

## Concept sketch

    ┌────────────────────────────────────────┐
    │                 (mic)                  │
    │   ┌──────────────────────────────┐     │
    │   │        480×320 SPI TFT       │     │
    │   └──────────────────────────────┘     │
    │    [S1]      [S2]      [S3]    [S4]    │
    │    (E1)      (E2)      (E3)    (E4)    │
    │  [PLAY] [STOP] [REC] [MODE] [<] [>]   │
    │                                        │
    │       [ ■  ■  ■  ■  ■  ■  ■  ■ ]       │
    │ (J)   [ ■  ■  ■  ■  ■  ■  ■  ■ ]  [F] │
    │       [ ■  ■  ■  ■  ■  ■  ■  ■ ]  [F] │
    │       [ ■  ■  ■  ■  ■  ■  ■  ■ ]       │
    │   [SHIFT]  [━━━━━ space ━━━━━] [SHIFT] │
    └────────────────────────────────────────┘

(J) = pitch/mod thumbstick — left of the grid, vertically centered on
the grid rows (synth pitch-wheel position). (F) = crossfader —
vertical, right of the grid, same centerline: a two-thumb performance
strip flanking the grid. Default mapping is top = A, bottom = B; any
other macro assignment stays brain-side.

## Hardware deltas vs NSR-1 rev A

Architecture unchanged: `Pi ──USB(OTG)── [Pico] ──I²C── peripherals`,
Pico stays bus master at 400 kHz on GP4/GP5. **Pico pin map is reused
verbatim** (encoders GP0–3/6–9 A/B, GP10–13 pushes; GP16/17 UART header
for rev B).

### I²C map (one bus, 400 kHz)

| Addr | Device | Count | Role |
|---|---|---|---|
| 0x20 | MCP23017 | 1 | grid keys 0–15 (rows 1–2: GPA0–7, GPB0–7) |
| 0x21 | MCP23017 | 1 | grid keys 16–31 (rows 3–4: GPA0–7, GPB0–7) |
| 0x22 | MCP23017 | 1 | function keys (13 inputs, 3 spare) |
| 0x48 | ADS1115 | 1 | AIN0 = thumbstick X (bend), AIN1 = Y (mod), AIN2 = crossfader, AIN3 → GND |
| 0x70 | HT16K33A | 1 | 32 grid LEDs, driver only |

Three expanders, same count as NSR-1 — the MCP23017 has 16 I/O pins, so
45 keys need all 48. One ADS1115 instead of three. Bring-up I²C scan
must list exactly: `0x20 0x21 0x22 0x48 0x70`.

### Key budget — 45 inputs

| Index | Note | Key |
|---|---|---|
| 0–31 | 36–67 | grid, row-major (top-left = 0) |
| 32, 33, 34 | 68, 69, 70 | PLAY, STOP, REC |
| 35 | 71 | MODE |
| 36, 37 | 72, 73 | < , > |
| 38–41 | 74–77 | soft keys S1–S4 |
| 42, 43 | 78, 79 | SHIFT-L, SHIFT-R |
| 44 | 80 | SPACE |

MCP #3 pin assignment (pins 0–12): PLAY, STOP, REC, MODE, <, >,
S1–S4, SHIFT-L, SHIFT-R, SPACE. All inputs single-ended on expander
pull-ups, active low — no matrix, no diodes, as rev A.

### LEDs

HT16K33A drives 32 LEDs (COM0–3 × ROW0–7), one per grid key, row-major —
same formula as NSR-1 (`leds.c`: LED i → RAM[i & 7] bit (i >> 3)),
just a larger count. **Series resistors 1 kΩ** (not NSR-1's 470 Ω):
32 × ~3 mA ≈ 96 mA worst case keeps the Pico's ~200 mA external budget
safe; 470 Ω at 32 LEDs would not. The A-variant's 28-SOP brings out
COM0–7 only; ROW0–2 double as the I²C address inputs (left floating →
address 0x70, all 8 ROWs stay usable).

### Panel dimensions (Choc at 14 mm pitch)

- Grid block: 8 × 14 = 112 mm wide; 4 rows + shift/space row = 5 × 14
  = 70 mm tall.
- Thumbstick (left margin) and vertical crossfader (right margin)
  flank the grid, both centered on its rows.
- Panel: **180 × 210 mm** (to-scale mockup: `nsr2/panel_mockup_nsr2.png`,
  regenerated by `nsr2/mockup_panel.py`) vs NSR-1's 400 × 150 mm — about
  two-thirds of the area in a portrait slab. Screen stays the 4.0"
  480×320 ILI9488 (same 240×160@2× UI) — decided over the 3.5" for
  eyesight.

## BOM delta vs NSR-1

| Change | Items |
|---|---|
| Removed | 2× ADS1115, 6× 10k pots, MX switch kit (39 switches, hot-swap sockets, keycaps) |
| Changed | MX kit → ~29× Choc switches + Choc hot-swap sockets + low-profile keycap set (incl. 1u ×2 + wide spacebar, translucent for under-socket LEDs); 16 → 32 LEDs, 470 Ω → 1 kΩ; HT16K33 → HT16K33A |
| Kept | Pico, 3× MCP23017, 1× ADS1115, thumbstick, 60 mm slide pot (crossfader), 4× EC11 encoders, mic capsule → codec |

Net: panel electronics land meaningfully below NSR-1's, dominated by
the MX→Choc kit swap. Power switch, LiPo, PowerBoost, display, codec
and Pi side are untouched.

## Firmware plan

One codebase, build-flag panel variant (`PANEL_NSR1` / `PANEL_NSR2`):

| File | Delta |
|---|---|
| `board_config.h` | NSR-2 `KEY_CHIPS` (3 chips, same count as NSR-1 — new maps), LED count 32, 1× ADS1115 channel map, default velocity source |
| `config.c` | power-up velocity source = fixed 0x08 @ 100 (crossfader is mix duty, not velocity); REPLY feature mask gains bit 3 |
| `keys.c` | chip count stays 3 (no logic change) |
| `leds.c` | count 16 → 32, same RAM formula |
| `ads1115.c` | 9 channels → 3, board-driven |
| `encoder.c`, `midi.c`, `config.h` SysEx layer, `main.c`, TinyUSB | unchanged |

## Protocol notes (v1, unchanged mechanics)

- Key → note mapping stays `note = 36 + index`; the NSR-2 index table
  above replaces NSR-1's.
- **CC 26 = crossfader** (the old "data slider" source), CC 1 =
  thumbstick Y, pitch bend = thumbstick X — same numbers as NSR-1.
- REPLY feature mask: bit 3 = "32-grid layout (NSR-2)". A brain gates
  its grid mapping on this bit at the QUERY handshake — **one brain
  binary serves both panels**, which is what makes the software
  "nearly identical" rather than "forked".
- Velocity source codes apply unchanged; NSR-2 defaults to fixed 100
  and the brain may SET_VELOCITY_SOURCE to the crossfader (0x00) or
  host register (0x09) as on NSR-1.

## Brain-side mapping (semantics)

- **Step mode**: 32 grid keys = 2 bars of 16ths, or 4 tracks × 8 steps
  (pageable, as NSR-1's 16-step window logic); shift+grid = track
  select / mute / scene launch as NSR-1.
- **MODE** toggles play ↔ step ↔ text entry — a toggle, not a
  shift-hold, so both hands stay free to play (NSR-1 rule).
- **Play mode**: scale-locked isomorphic layout on the 4×8 grid (NSR-1's
  chromatic piano has no grid equivalent).
- **Text entry**: grid = QWERTY-flavored quasi-keyboard (4×8: QWERTYUI /
  ASDFGHJK / ZXCVBNM␣␣ / punctuation+enter+backspace), spacebar types
  space — feeds the existing EditBox/VirtualKeyboard flow.
- Emulator first, as always: `--panel=nsr2` sim profile rendering the
  4×8 layout, before any PCB exists.

## Resolved design calls

1. **MODE** — 6th key on the transport line (index 35 / note 71).
2. **Crossfader** — vertical at the grid's right edge, centered on the
   grid rows; fits the ~36 mm side margin where a horizontal 60 mm
   fader would force a full-width row and a taller panel.
3. **Thumbstick** — left of the grid, same centerline; synth
   pitch-wheel position, reachable by either hand's thumb, clear of
   the shift/space row.
4. **Screen** — 4.0" (eyesight priority over ~15 mm width saving).
5. **Spacebar** — one Choc switch under a wide (~3u) cap; slight cap
   tilt at the extremes is acceptable for a text-entry key.

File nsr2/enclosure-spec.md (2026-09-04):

# NSR-2 enclosure specification — 3D printed

The faceplate **is** the IO PCB (deep-red soldermask + cream silk), so
the printed parts are only the body: a bottom tray with walls, standoffs
at two levels, and the rear-edge cutouts. Two printed pieces total.

## Construction

- **Tray** (one print): floor + four walls + standoffs. M3 heat-set
  inserts for the IO faceplate lip and the brain-board standoffs.
- **Lid** = IO faceplate PCB, dropped into the tray lip and secured with
  8× M3 (corners + offset mid pairs at x30/x150, matching the board's
  mounting holes).
- No separate top bezel: the PCB edge-to-wall gap is 1.5 mm all around;
  the tray lip overlaps the faceplate edge by 2 mm.

## Dimensions

| | mm |
|---|---|
| IO faceplate (lid) | 180 × 210 × 1.6 |
| Internal floor | 183 × 213 (1.5 mm clearance) |
| Wall thickness | 2.4 (3 perimeters @ 0.8) |
| External W × D | ≈ 188 × 218 |
| External height | ≈ 27–28 |

## Height stack-up (from the floor up)

| Level | Contents | Height |
|---|---|---|
| 0 | floor (1.6) | 1.6 |
| 1 | battery pouch, in side floor pockets (see placement) | ~8–10 |
| 2 | brain board: PCB 1.6 + 2×20 header 8.5 + Pi Zero ~3 + Audio Injector ~3 | ≈ 18 |
| 2 | Pico assembly under the IO top-right: header 8.5 + Pico ≈ 10 | ≈ 10 |
| 2 | EC11 bodies under the encoder row | ≈ 10.5 |
| 2 | Choc sockets + LEDs under the grid zone | ≈ 4.5 |
| 3 | IO faceplate lip | +2 |

Max under-faceplate stack ≈ 18 mm (brain) + clearance → internal ~20 mm
at the lid level → external ≈ 27–28 mm total. The instrument stays a
flat slab — no wedge in rev A (a rear wedge/stand is a print variant,
same tray, taller rear walls).

## Floor placement zones (top view, panel coordinates)

- **Brain board**: x 40–140, y 0–85 — under the screen/soft-key/encoder
  zone, on 18 mm standoffs, screen header facing up into the faceplate
  window.
- **Battery pouch (2000–3000 mAh, ~34 × 60 × 8)**: side floor pocket,
  x 0–32 or x 148–180 strip beside the encoder/transport rows — clear
  of EC11 bodies (which occupy x 34–146 under y ≈ 95–110), the brain
  stack, and the grid sockets (grid zone under-IO is only ~4.5 mm).
- **Pico**: bottom face of the IO board, top-right; its USB cable runs
  ~100 mm internally down to the brain board's USB-A receptacle.
- **Mic capsule**: glued behind the faceplate's ⌀3 mic hole (90, 5.5),
  foam ring, pigtail to brain J5.

## Rear-wall cutouts (y = 0 edge)

| Cutout | Size | For |
|---|---|---|
| DIN-5 MIDI IN + OUT | 2× ⌀16.5, spaced per brain J2/J3 | DIN sockets, flush |
| Power switch | slot 7 × 13 | brain SW1 actuator |
| Charge port | micro-USB slot 8 × 4 | PowerBoost input |
| SD card slot | slot 13 × 3, positioned over the Pi Zero's µSD edge | re-imaging without opening the box |
| BOOTSEL / RUN | ⌀3.5 hole top edge over Pico SW1 | firmware recovery (NSR-1 convention) |

No front or side cutouts — the USB link is internal; line out/in live on
the Audio Injector's rear 3.5 mm jacks, which face the rear wall: add a
double 3.5 mm cutout aligned with the codec jack row (verify Y position
against the actual Audio Injector Zero jack placement at layout time).

## Fastening & print notes

- M3 heat-set inserts (brass): 8× lid lip, 4× brain standoffs.
- Material: **black PETG** (contrast with the red faceplate) or
  `--red-dark` PETG for a monolith — aesthetic call.
- 0.2 mm layers, 3 perimeters, 15% gyroid; standoffs printed solid.
- Tolerances: holes +0.2 mm, slots +0.3 mm, lip fit test piece first.
- Feet: 4× adhesive silicone ⌀10 × 2 (or printed nubs).

## Open items

1. **Audio Injector Zero exact jack positions** — needed before the rear
   3.5 mm cutout is finalized (measure the real board).
2. **PowerBoost orientation** — its micro-USB charge port must align with
   the rear cutout; pick the J6 header rotation at layout time.
3. Wedge/stand variant — deferred (rev A is a flat slab).
4. Speaker? None — headphone/line only, as NSR-1 (battery budget).

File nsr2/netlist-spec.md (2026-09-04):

# NSR-2 netlist specification — rev A

Definitive hardware↔firmware contract for the two NSR-2 boards. Firmware
side lives in `panel-fw/src/board_config.h` (`PANEL_NSR2` variant); any
change here must update that file (and vice versa) in the same commit.

Manufacturing: 2-layer, 1.6 mm, ENIG, **deep-red soldermask** (bokontep
`--red-dark` family) with cream/white silkscreen — on the IO board the
PCB **is the faceplate**: red mask + cream print replace the aluminum
panel. SMD placed by the fab (JLC economic assembly); every
hand-soldered part is THT.

## Architecture

    ┌─ BRAIN board (100×80) ─────────────┐      ┌─ IO board / faceplate (180×210) ──┐
    │ Pi Zero 2W (2×20 female headers)   │      │ Pico (2×20 female, micro-B flush  │
    │  └ Audio Injector Zero stacks on   │ USB  │   top edge) — USB-MIDI panel      │
    │    the Pi's 40-pin header          │ A→µB │  ├ 3× MCP23017   45 keys          │
    │ ILI9488 4.0" SPI (right-angle hdr) │cable │  ├ HT16K33A    32 LEDs           │
    │ 2× DIN-5 MIDI (6N138 in, R out)    │─────►│  ├ 1× ADS1115    3 analog         │
    │ PowerBoost 1000C + LiPo + switch   │      │  ├ 4× EC11 encoders (XH)          │
    │ USB-A receptacle = Pi OTG breakout │      │  └ 45× Choc hot-swap sockets      │
    └────────────────────────────────────┘      └───────────────────────────────────┘

Two boards exactly as proposed: **Brain** (zero + screen + codec + power +
DIN MIDI) and **IO** (pico + buttons + encoders + LEDs + analog). The only
inter-board link is one USB cable (5V / D+ / D− / GND) — the panel stays an
independently testable USB-MIDI device, as in NSR-1.

I²C map (one bus on the IO board, 400 kHz, Pico master):

| Addr | Device | Role |
|---|---|---|
| 0x20 | MCP23017 | grid keys 0–15 (rows 1–2: GPA0–7, GPB0–7) |
| 0x21 | MCP23017 | grid keys 16–31 (rows 3–4: GPA0–7, GPB0–7) |
| 0x22 | MCP23017 | function keys: 13 inputs (GPA0–5, GPA6–7, GPB0–4), 3 spare |
| 0x48 | ADS1115 | AIN0 = thumbstick X (bend), AIN1 = Y (mod), AIN2 = crossfader, AIN3 → GND |
| 0x70 | HT16K33A | 32 LED driver only (28-SOP brings out COM0–7; address on ROW0–2 at POR, left floating = 0x70) |

**Three expanders, as NSR-1** — the MCP23017 has 16 I/O pins, so 45 keys
need 48 expander pins. I²C pull-ups 4.7 kΩ on the IO board only.

Power: PowerBoost 1000C → 5V rail on the brain board feeds the Pi's 5V
pins; the Pi's OTG port powers the IO board (~115 mA worst case: 32 LEDs
at 1 kΩ + Pico + expanders + HT16K33A + ADS). LiPo 2000–3000 mAh on the
PowerBoost's JST, panel/rear power switch THT on the brain board.

---

## Brain board — 100 × 80 mm

M3 holes (3.2 mm) at (5,5) (95,5) (5,75) (95,75). Pi Zero 2W on 2×20
machined female headers (Audio Injector Zero stacks on the Pi's exposed
male header above it — codec, bias and I2S never touch this board).

### Pi net usage

| Pi pin | Net / function |
|---|---|
| 2, 4 | +5V rail from PowerBoost |
| 1, 17 | 3V3 → screen module logic/backlight |
| 6, 9, 14, 20, 25, 30, 34, 39 | GND |
| 8 / 10 (GPIO14/15) | DIN MIDI out / in (31250 baud, `pi3-disable-bt`) |
| 24 (GPIO8 CE0), 19 (GPIO10 MOSI), 23 (GPIO11 SCLK) | screen SPI0 |
| 18 / 22 / 13 (GPIO24/25/27) | screen DC / RST / BL |
| 5 (GPIO3) | optional shutdown button (rootfs read-only, per design.md) |

### Connectors (THT)

| Ref | Type | Pinout |
|---|---|---|
| J1 | USB-A receptacle | Pi OTG breakout: 1=VBUS, 2=D−, 3=D+, 4=GND (+ shell GND) — short A→micro-B cable to the IO board's Pico |
| J2, J3 | DIN-5 ×2 | MIDI OUT (TX + 33 Ω → pin 4/5, 2=GND) · MIDI IN (6N138: 5→RX, 2/3 opto input + 220 Ω/1 kΩ network) |
| J4 | 2×8 right-angle header | ILI9488 module: VCC(3V3), GND, CS, RST, DC, MOSI, SCLK, LED — plugs up to the screen module fixed in the IO faceplate window |
| J5 | XH-2P | electret mic capsule → Audio Injector Zero mic/line-in jack (3.5 mm pigtail), strain relief |
| SW1 | SPDT THT, rear edge | power switch (PowerBoost EN) |
| J6 | 2×5 header | PowerBoost 1000C mount (5V, GND, EN, LiPo± pigtail to its JST) |

The brain board sits **below** the IO faceplate on enclosure standoffs
(≈18 mm level) under the screen/encoder zone. The Pi's microSD slot on
the Zero's underside stays reachable through an enclosure slot — align
it with the rear wall.

### ICs and discretes

| Ref | Part | Notes |
|---|---|---|
| U1 | 6N138 | MIDI-IN optocoupler (never feed a bare UART) |
| U2 | USBLC6-2SC6 | ESD on USB D+/D− at J1 |
| R1–R5 | MIDI network: 33 Ω, 220 Ω, 1 kΩ, 2× 10 kΩ | per MIDI 1.0 electrical spec |
| C1–C3 | 100 nF 0805 | decoupling U1, U2, screen header |

---

## IO board (faceplate) — 180 × 210 mm

M3 holes at (5,5) (175,5) (30,5) (150,5) (5,205) (30,205) (150,205)
(175,205) — corners plus offset mid pairs (x30/x150), keeping every
standoff clear of the screen window, the mic hole and the shift/space
row. Board outline matches `nsr2/panel_mockup_nsr2.png` with one addition:
a **screen window** cut out of Edge.Cuts at (40, 8)–(140, 80) — the
4.0" ILI9488 module mounts to the faceplate with 4× M2 screws over the
window and connects **down** to the brain board's right-angle header
(the brain board rides ~18 mm below on enclosure standoffs). Mic hole
⌀3 mm at (90, 5.5); capsule glues behind it, wired to brain J5.
Placement by face: Choc sockets + LEDs on the **top** face; all ICs,
Pico and connectors on the **bottom** face (clean faceplate top). Pico
bottom-mounted on 2×20 female headers, micro-B flush with the top edge
(short cable to the brain board's USB-A — internal, no external port).

### Pico pin map — identical to NSR-1 rev A (reused verbatim)

| Pico pin | GPIO | Net / function |
|---|---|---|
| 1 / 2 | GP0 / GP1 | ENC1 A / B |
| 4 / 5 | GP2 / GP3 | ENC2 A / B |
| 6 / 7 | GP4 / GP5 | I²C SDA / SCL (bus master) |
| 9 / 10 | GP6 / GP7 | ENC3 A / B |
| 11 / 12 | GP8 / GP9 | ENC4 A / B |
| 14–17 | GP10–13 | ENC1–4 push |
| 19 / 20 | GP14 / GP15 | spare (rev B) |
| 21 / 22 | GP16 / GP17 | UART link header (optional serial transport) |
| 24–27 | GP18–21 | spare (rev B) |
| 30 | RUN | SW1 reset button → GND |
| 36 | 3V3(OUT) | +3V3 rail |
| 3,8,13,18,23,28,38 | — | GND (use ≥ 4) |

### Key expander maps

MCP #1 @0x20 — grid rows 1–2:

| Pins | Keys |
|---|---|
| GPA0–7 | grid 0–7 (row 1, top) |
| GPB0–7 | grid 8–15 (row 2) |

MCP #2 @0x21 — grid rows 3–4:

| Pins | Keys |
|---|---|
| GPA0–7 | grid 16–23 (row 3) |
| GPB0–7 | grid 24–31 (row 4, bottom) |

MCP #3 @0x22 — function keys (A0→VDD, A1/A2→GND):

| Pin | Key | | Pin | Key |
|---|---|---|---|---|
| GPA0 | PLAY (32) | | GPB0 | S3 (40) |
| GPA1 | STOP (33) | | GPB1 | S4 (41) |
| GPA2 | REC (34) | | GPB2 | SH-L (42) |
| GPA3 | MODE (35) | | GPB3 | SH-R (43) |
| GPA4 | < (36) | | GPB4 | SPACE (44) |
| GPA5 | > (37) | | GPB5–7 | spare (test points) |
| GPA6 | S1 (38) | | | |
| GPA7 | S2 (39) | | | |

All 45 keys: **Kailh Choc V1 hot-swap sockets** (CPG151101S11), switch to
GND, expander pull-ups, active low — no matrix, no diodes. Soft/transport
keys are 1u Choc like the grid (one switch type for the whole panel).

### LEDs — documented deviation from the mockup

**Choc switches have no LED slot** (unlike NSR-1's MX). Per-key lighting
is under-socket instead: 32× 0603 LED centered under each grid socket,
glowing through **translucent/clear low-profile caps**. Drive unchanged:
HT16K33A COM0–3 × ROW0–7, LED i → RAM[i & 7] bit (i >> 3), i = grid index
(row-major), **1 kΩ** series (32 × ~3 mA ≈ 96 mA worst case — inside the
Pico's ~200 mA external budget; 470 Ω would not be).

### Connectors (all JST-XH, THT)

| Ref | Type | Pinout |
|---|---|---|
| J1 | XH-4P | thumbstick: 1=GND, 2=3V3, 3=VRx, 4=VRy |
| J2 | XH-3P | crossfader: 1=GND, 2=wiper, 3=3V3 |
| J3–J6 | XH-5P ×4 | encoders 1–4: 1=A, 2=B, 3=C→GND, 4=D→SW, 5=E→GND (tie 5–3) |
| J7 | XH-4P | UART link: 1=3V3, 2=GND, 3=TX(GP16), 4=RX(GP17) |

No USB receptacle on this board — the brain's USB-A cable plugs into the
**Pico's own micro-B connector** (flush with the top edge); VBUS then
appears on Pico header pin 40 and feeds the +5V rail.

### ICs and discretes

| Ref | Part | Notes |
|---|---|---|
| U1 | MCP23017 (SSOP-28) @0x20 | A0–A2→GND; GPA=keys 0–7, GPB=keys 8–15 |
| U2 | MCP23017 (SSOP-28) @0x21 | A0→VDD, A1/A2→GND; GPA=keys 16–23, GPB=keys 24–31 |
| U3 | MCP23017 (SSOP-28) @0x22 | A1→VDD, A0/A2→GND; function keys per table above |
| U4 | HT16K33A (SSOP-28) @0x70 | LED driver only; custom symbol in `nsr2.kicad_sym` (28-SOP has COM0–7 only; ROW0–2 double as address inputs — leave floating for 0x70) |
| U5 | ADS1115 (MSOP-10) @0x48 | ADDR→GND; AIN0=VRx, AIN1=VRy, AIN2=fader, AIN3→GND, RC filtered |
| R1, R2 | 4.7 kΩ 0805 | I²C pull-ups — this board only |
| R-f ×3 | 10 kΩ 0805 | series, wiper → AINx (RC at the ADS1115 side) |
| C-f ×3 | 100 nF 0805 | AINx → GND |
| LED 1–32 | 0603 red | under grid sockets; anode → COM(i>>3), cathode → 1 kΩ → ROW(i&7) |
| R 1–32 | 1 kΩ 0805 | LED series |
| C1–C4 | 100 nF 0805 | decoupling U1–U4 |

Unused ADS1115 input (AIN3) → GND. ADC_VREF (pin 35) NC.

---

## BOM split

- **Fab assembles (SMD):** IO — 3× MCP23017, ADS1115, HT16K33A, 32× 0603
  LED + 32× 1 kΩ, 3× 10 k + RC set, 2× 4.7 k, decoupling; brain — 6N138,
  USBLC6, MIDI R network, decoupling.
- **Hand-solder (THT):** 45× Choc hot-swap sockets, Pico + Pi female
  headers, screen right-angle header, USB-A receptacle, 2×
  DIN-5, all XH connectors, EC11s (panel-wired via XH), PowerBoost,
  power switch, tact (RUN).
- **Modules (bought, not designed):** Pi Zero 2W, Audio Injector Zero,
  ILI9488 4.0" SPI module, Pico, thumbstick, 60 mm slide pot, LiPo +
  PowerBoost 1000C, translucent Choc cap set (incl. 2× 1u + 1× ~3u).

## Schematics

The schematics are **generated**: `nsr2/tools/gen_schematics.py` emits
both `.kicad_sch` files (and the `nsr2.kicad_sym` project library with
the custom HT16K33A symbol) from this spec — rerun it after any change
here, then re-check with `kicad-cli sch erc`. Status: **0 ERC errors**
on both boards; remaining warnings are benign and enumerated in
`nsr2/README.md` (embedded-copy vs library mismatch, the intentional
single-pin MIC label, footprint names to finalize at layout: DIN-5
sockets, power switch, Choc hot-swap sockets). Board outlines
(180×210 faceplate with screen window, 100×80 brain) are already
captured in the `.kicad_pcb` files. See `nsr2/README.md` for the
collaboration contract (what may be hand-edited and when).

## Bring-up checklist

1. IO I²C scan must list exactly: `0x20 0x21 0x22 0x48 0x70`.
2. LEDs: Note On ch2 (note 0–31) — LED i glows under grid key i+1.
3. Keys: every key emits 36 + index (protocol table); ghost-free by
   construction (no matrix).
4. Analog: sweep thumbstick X/Y + crossfader; verify bend, CC 1, CC 26.
5. Encoders: detents → CC 16–19 (65/63); pushes → CC 32–35.
6. GRV SysEx: QUERY/REPLY (feature bit 3 set = NSR-2 layout),
   velocity-source switching, persistence round-trip.
7. Brain: USB-A port enumerates the Pico; MIDI DIN loopback; screen on
   SPI0 at 32 MHz; boot-to-sound with the codec stacked.
8. UART header continuity (GND/3V3/TX/RX) for the future serial transport.

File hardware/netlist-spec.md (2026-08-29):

# Hardware netlist specification — rev A

Definitive hardware↔firmware contract for the two control-surface boards.
Firmware side lives in `panel-fw/src/board_config.h`; any change here must
update that file (and vice versa) in the same commit.

Manufacturing target: 2-layer, 1.6 mm, ENIG, green→**deep-red soldermask**
(faceplate aesthetic), white silkscreen. SMD parts placed by the fab
(PCBWay/JLC economic assembly); every hand-soldered part is THT.

## Architecture

    Pi Zero 2W ──USB(OTG)── [Pico] ──I2C──┬── 3× MCP23017   39 keys, uniform
             (power+MIDI)   │  GP4/GP5    ├── HT16K33      16 step LEDs
                            │             └── 3× ADS1115    9 analog inputs
                            ├─ 4× EC11 encoders (direct GPIO)
                            ├─ RUN button, UART link header (optional serial)
                            └─ micro-USB → Pi OTG port

All 39 keys are **single-ended inputs on MCP23017 expanders** (switch to GND,
expander pull-ups, active low): no matrix, no per-key diodes, one uniform
scan path in firmware. The HT16K33 is a pure LED driver. This supersedes the
design.md rev-0 idea of HT16K33 key scanning (documented deviation).

I²C map (one bus, 400 kHz):

| Addr | Device | Board | Role |
|---|---|---|---|
| 0x20 | MCP23017 | keyboard | white keys 0–15 |
| 0x21 | MCP23017 | keyboard | black keys 16–26, shifts 38/39, 3 spare |
| 0x22 | MCP23017 | control | function keys + joystick SW, 5 spare |
| 0x48 | ADS1115 | control | pots 1–4 |
| 0x49 | ADS1115 | control | pots 5–6, slider, joystick Y |
| 0x4A | ADS1115 | control | joystick X (pitch bend) |
| 0x70 | HT16K33  | keyboard | 16 LED driver only |

Power: Pico is powered from the Pi's OTG port over its own micro-USB;
everything runs from 3V3(OUT) (pin 36). Budget: LEDs 16×6 mA ≈ 96 mA +
4×MCP + 3×ADS + HT16K33 ≈ **~130 mA worst case** — inside the Pico's ~200 mA
external budget. Keep LED resistors ≥ 470 Ω.

---

## Control board — 90 × 70 mm

M3 mounting holes (3.2 mm) at (5,5) (85,5) (5,65) (85,65).
Pico on 2×20 machined female headers (J1A pins 1–20, J1B pins 21–40),
module micro-USB flush with the **bottom edge** (cable to Pi OTG), BOOTSEL
reachable through an enclosure hole.

### Pico pin map

| Pico pin | GPIO | Net / function |
|---|---|---|
| 1 / 2 | GP0 / GP1 | ENC1 A / B |
| 4 / 5 | GP2 / GP3 | ENC2 A / B |
| 6 / 7 | GP4 / GP5 | I²C SDA / SCL (bus master) |
| 9 / 10 | GP6 / GP7 | ENC3 A / B |
| 11 / 12 | GP8 / GP9 | ENC4 A / B |
| 14–17 | GP10–13 | ENC1–4 push |
| 19 / 20 | GP14 / GP15 | spare (rev B) |
| 21 / 22 | GP16 / GP17 | UART link header (optional serial transport) |
| 24–27 | GP18–21 | spare (rev B) |
| 29 | GP22 | spare (rev B) |
| 30 | RUN | SW1 reset button → GND |
| 31–34 | GP26–28 | spare (rev B; ADC-capable) |
| 36 | 3V3(OUT) | +3V3 rail |
| 3,8,13,18,23,28,38 | — | GND (use ≥ 4) |

### Connectors (all JST-XH, THT)

| Ref | Type | Pinout |
|---|---|---|
| J2–J7 | XH-3P ×6 | pots 1–6: 1=GND, 2=wiper, 3=3V3 |
| J8 | XH-3P | data slider: 1=GND, 2=wiper, 3=3V3 |
| J9 | XH-4P | joystick module: 1=GND, 2=3V3, 3=VRx, 4=VRy |
| J10–J13 | XH-5P ×4 | encoders 1–4: 1=A, 2=B, 3=C→GND, 4=D→SW, 5=E→GND (tie 5–3 on board) |
| J14 | XH-4P | keyboard link: 1=3V3, 2=GND, 3=SDA, 4=SCL |
| J15 | XH-4P | UART link: 1=3V3, 2=GND, 3=TX(GP16), 4=RX(GP17) |
| J16–J25 | XH-2P ×10 | function keys: 1=U4 GPIO, 2=GND (PLAY, STOP, REC, MODE, <, >, S1–S4 in that order) |
| J26 | XH-2P | joystick SW |
| J27, J28 | XH-2P | spare inputs (U4 pins 12–15 remain for rev B) |

### ICs and discretes

| Ref | Part | Notes |
|---|---|---|
| U1 | ADS1115 (VSSOP-10) @0x48 | ADDR→GND. AIN0–AIN3 ← pots 1–4 |
| U2 | ADS1115 @0x49 | ADDR→3V3. AIN0←pot5, AIN1←pot6, AIN2←slider, AIN3←VRy |
| U3 | ADS1115 @0x4A | ADDR→SDA. AIN0←VRx; AIN1–3 → GND |
| U4 | MCP23017 (SSOP-28 or SPDIP-28) @0x22 | ADDR strap A1→VDD, A0/A2→GND. All 16 GPA/B inputs (J16–J28) |
| SW1 | 6 mm tact, THT | RUN → GND |
| R-f ×9 | 10 kΩ 0805 | series, wiper → AINx (RC filter, place at the ADS1115 side) |
| C-f ×9 | 100 nF 0805 | AINx → GND |
| R1, R2 | 4.7 kΩ 0805 | I²C pull-ups — **control board only**, never duplicate on keyboard |
| C1–C4 | 100 nF 0805 | decoupling, one per IC |

Unused ADS1115 inputs → GND. ADC_VREF (pin 35) NC.

---

## Keyboard board — 356 × 62 mm

M3 holes at (5,5) (351,5) (5,57) (351,57).
29 MX hot-swap sockets (Kailh, THT): SH-L, 16 whites, 11 blacks, SH-R.
Whites at 19.05 mm pitch; blacks on the upper row (y offset ≈ −22 mm) at the
piano gaps {1,2, 4,5,6, 8,9, 11,12,13} plus one far-right position; shifts at
the row ends. Gateron Red / Silent Red, 3 mm LED slot in whites.

| Ref | Part | Role |
|---|---|---|
| U1 | MCP23017 @0x20 (A0–A2→GND) | GPA/B = white keys 0–15, in white-key order |
| U2 | MCP23017 @0x21 (A0→VDD) | pins 0–10 = blacks 16–26, pins 11/12 = shifts 38/39, 3 spare (test points) |
| U3 | HT16K33 (SOP-28) @0x70 | LED driver only — key-scan RAM unused |
| J1 | XH-4P | I²C link to control board (same pinout as J14) |
| LED 1–16 | 3 mm THT, in switch slots | anode → COM(i>>3), cathode → R 470 Ω → ROW(i&7), i = white key index − 1 |
| R1–R16 | 470 Ω 0805 | LED series |
| C1–C3 | 100 nF 0805 | decoupling U1–U3 |

LED/HT16K33 mapping must stay in lockstep with `panel-fw/src/leds.c`
(LED i → RAM[i & 7] bit (i >> 3)). No I²C pull-ups on this board.

---

## BOM split

- **Fab assembles (SMD):** keyboard — 2× MCP23017 (SPDIP-28 if keeping it
  fully hand-solderable, else SOIC-28), HT16K33, 16× 470 Ω, 3× 100 nF;
  control — 3× ADS1115, MCP23017 (SSOP-28), 9× 10 k + 13× 100 nF, 2× 4.7 k.
- **Hand-solder (THT):** all hot-swap sockets, all XH connectors, Pico
  sockets, tact switch, LEDs, encoder/pot/slider/joystick modules (wired).

## Bring-up checklist

1. I²C scan must list exactly: 0x20 0x21 0x22 0x48 0x49 0x4A 0x70.
2. LEDs: Note On ch2 (note 0–15) — verify LED i maps to white key i+1.
3. Keys: every key emits 36 + index (protocol table); chords ghost-free by
   construction (no matrix).
4. Analog: sweep each pot/slider/joystick; verify CC 20–26, CC 1, bend.
5. Encoders: detents → CC 16–19 (65/63); pushes → CC 32–35.
6. GRV SysEx: QUERY/REPLY, velocity source switching, persistence round-trip.
7. UART header continuity (GND/3V3/TX/RX) for the future serial transport.

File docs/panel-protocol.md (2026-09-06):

# Panel ↔ Brain Protocol (USB-MIDI)

The panel module (Pico) presents as a USB-MIDI device named `groovebox-panel`.
All panel→brain traffic rides this protocol; the brain sends LED state back
on channel 2. The emulator's sim backend emits/consumes the same logical
messages, so app code never cares which side is real.

Channel 1 = panel → brain. Channel 2 = brain → panel (LEDs).

## Panel → brain

### Keys (55 total, rev B)

Every panel key sends Note On (press, velocity = current value of the
configured **velocity source**, 1–127 — slider by default, see
[Panel configuration](#panel-configuration-sysex-id-0x7d)) and Note Off
(release). Note number = 36 + key index.

| Index | Note | Key |
|---|---|---|
| 0–15 | 36–51 | white keys 1–16 (piano row, always playable) |
| 16–26 | 52–62 | black keys, left to right (C♯ pattern order) |
| 27–29 | 63–65 | transport: PLAY, STOP, REC |
| 30 | 66 | joystick push |
| 31 | 67 | MODE (keyboard scale-lock toggle) |
| 32, 33 | 68, 69 | < , > |
| 34–37 | 70–73 | soft keys S1–S4 |
| 38, 39 | 74, 75 | SHIFT-L, SHIFT-R |
| 40–55 | 76–91 | **step row 1–16** (rev B: dedicated sequencer row under the piano) |

Both shifts are logically identical; the brain may merge them.

### Analog (CC, channel 1, 7-bit MSB only for rev A)

| CC | Source |
|---|---|
| 20 | pot CUTOFF |
| 21 | pot RESONANCE |
| 22–25 | ~~pots ATTACK/DECAY/SUSTAIN/RELEASE~~ — removed in rev B2 (ADSR moved to encoders 5–8); reserved |
| 26 | data slider (default velocity source — see Panel configuration) |
| 1  | joystick Y (mod) |
| pitch bend | joystick X (spring-returned, center = 8192) |

### Encoders (relative CC, channel 1)

| CC | Source |
|---|---|
| 16–23 | encoder 1–8 rotation: two's-complement relative (64 = no movement, 65 = +1 detent, 63 = −1 detent). Encoders 5–8 = amp-ENV A/D/S/R (rev B2) |
| 32–39 | encoder 1–8 push: 127 on press, 0 on release |

## Brain → panel (LEDs, channel 2)

Note On/Off on channel 2. Notes 0–15 = **step-row LEDs**, 16–31 =
**white-key LEDs** (NSR-1 rev B). Velocity ignored for rev A (single
intensity); velocities 1–127 may later map to PWM brightness.

CC 27 on channel 2 is the **host velocity register**: the brain writes the
live velocity value (1–127) it wants stamped on subsequent Note Ons while
the velocity source is `host register` (see Panel configuration). All other
channel-2 CCs are reserved.

## Panel configuration (SysEx, ID 0x7D)

Panel routing is host-configurable via vendor SysEx on the free
non-commercial manufacturer ID `0x7D`. Configuration is **routing, not
semantics**: the panel still only reports physical events — the brain merely
chooses which physical value stamps Note On velocity. All musical meaning
stays app-side (final section).

Frame: `F0 7D 47 52 56 <cmd> [args…] F7` — `47 52 56` is ASCII `GRV`.

| Cmd | Name | Args | Effect |
|---|---|---|---|
| 0x01 | SET_VELOCITY_SOURCE | `src` (+ `value` when `src` = 0x08) | velocity source for Note On, captured at the press instant |
| 0x02 | QUERY | — | panel replies with 0x03 (below) |
| 0x03 | REPLY | `proto_ver`, `feature_mask` | panel → brain: protocol version (currently 1) and capability bits |
| 0x04 | SET_PERSISTENCE | `mode` | 0 = volatile (default), 1 = save-on-change |
| 0x7F | RESET_DEFAULTS | — | velocity source = slider, persistence = volatile; erases any saved config |

Velocity source codes for 0x01:

| `src` | Meaning |
|---|---|
| 0x00 | data slider (power-up default — rev A behavior) |
| 0x01–0x02 | pot 0–1: CUTOFF / RESONANCE (the CC 20–21 sources) |
| 0x03–0x06 | legacy rev A pots — clamp to the nearest real pot (rev B2: only two pots exist) |
| 0x07 | joystick Y (the CC 1 source) |
| 0x08 | fixed value, next byte 1–127 |
| 0x09 | host register (CC 27 on channel 2) |

Feature mask bits (REPLY): bit 0 = velocity source assignment, bit 1 =
config persistence, bit 2 = host velocity register. A brain that wants
optional behavior gates on these bits, not on the version byte.

Rules:

- **Volatile by default.** With persistence off, the panel powers up with
  velocity source = slider and no stored config. The brain re-sends its
  configuration after the QUERY handshake at boot and on mode changes.
- **Save-on-change.** With persistence on, each accepted config command is
  written to flash and restored at power-up. The firmware coalesces writes
  (at most one flash write per second of sustained changes) to spare the
  flash; the brain should still avoid high-rate configuration streams.
- **Unknown commands are ignored, never rejected** — a rev B panel may
  accept commands an older brain does not know, and vice versa. QUERY plus
  the feature bits is the discovery mechanism.
- **Unknown `src` codes fall back to the slider**, never to a dead velocity.

## NSR-2 panel variant

NSR-2 is the compact portrait panel (180x210 mm, 4x8 Choc grid — see
`docs/nsr2-design.md`). Same protocol v1 mechanics; different key map,
LED count, and defaults.

### Key map (45 keys, channel 1, note = 36 + index)

| Index | Note | Key |
|---|---|---|
| 0–31 | 36–67 | grid keys, row-major (top-left = 0) |
| 32, 33, 34 | 68, 69, 70 | PLAY, STOP, REC |
| 35 | 71 | MODE |
| 36, 37 | 72, 73 | < , > |
| 38–41 | 74–77 | soft keys S1–S4 |
| 42, 43 | 78, 79 | SHIFT-L, SHIFT-R |
| 44 | 80 | SPACE (wide bar) |

### Differences vs NSR-1

- **No pots, no data slider.** The 60 mm control is a **crossfader** on
  **CC 26** (same channel/index as NSR-1's slider). Thumbstick stays:
  CC 1 (Y / mod) and pitch bend (X), unchanged.
- **32 LEDs** (one per grid key): brain → panel note on/off on channel 2,
  note number = LED index **0–31** (row-major, same formula as NSR-1
  extended to 4x8).
- **Velocity source default = fixed 100** (`src` 0x08 @ 100) — the
  crossfader is mix/performance duty by default; the brain may
  SET_VELOCITY_SOURCE to 0x00 (crossfader) or 0x09 (host register) as
  on NSR-1.
- **REPLY feature mask gains bit 3 = "32-grid layout (NSR-2)"** so one
  brain binary gates its grid mapping on the QUERY handshake.
- MODE cycles three keyboard-row modes: **step → play → text** (NSR-1
  has step ↔ play only). Play mode is a scale-locked isomorphic grid
  (row up = +4 semitones, column = +1, base C3); text mode is a
  QWERTY-flavored grid feeding the EditBox flow.

## Semantics live in the brain

The panel is dumb: it reports physical events, nothing more. Key → musical
note mapping (scale/octave/play-vs-step mode), shift layers, velocity
interpretation (the panel's source binding is mere routing — see Panel
configuration), and all mode logic are app-side. This keeps the panel
firmware stable and the behavior firmware-free.

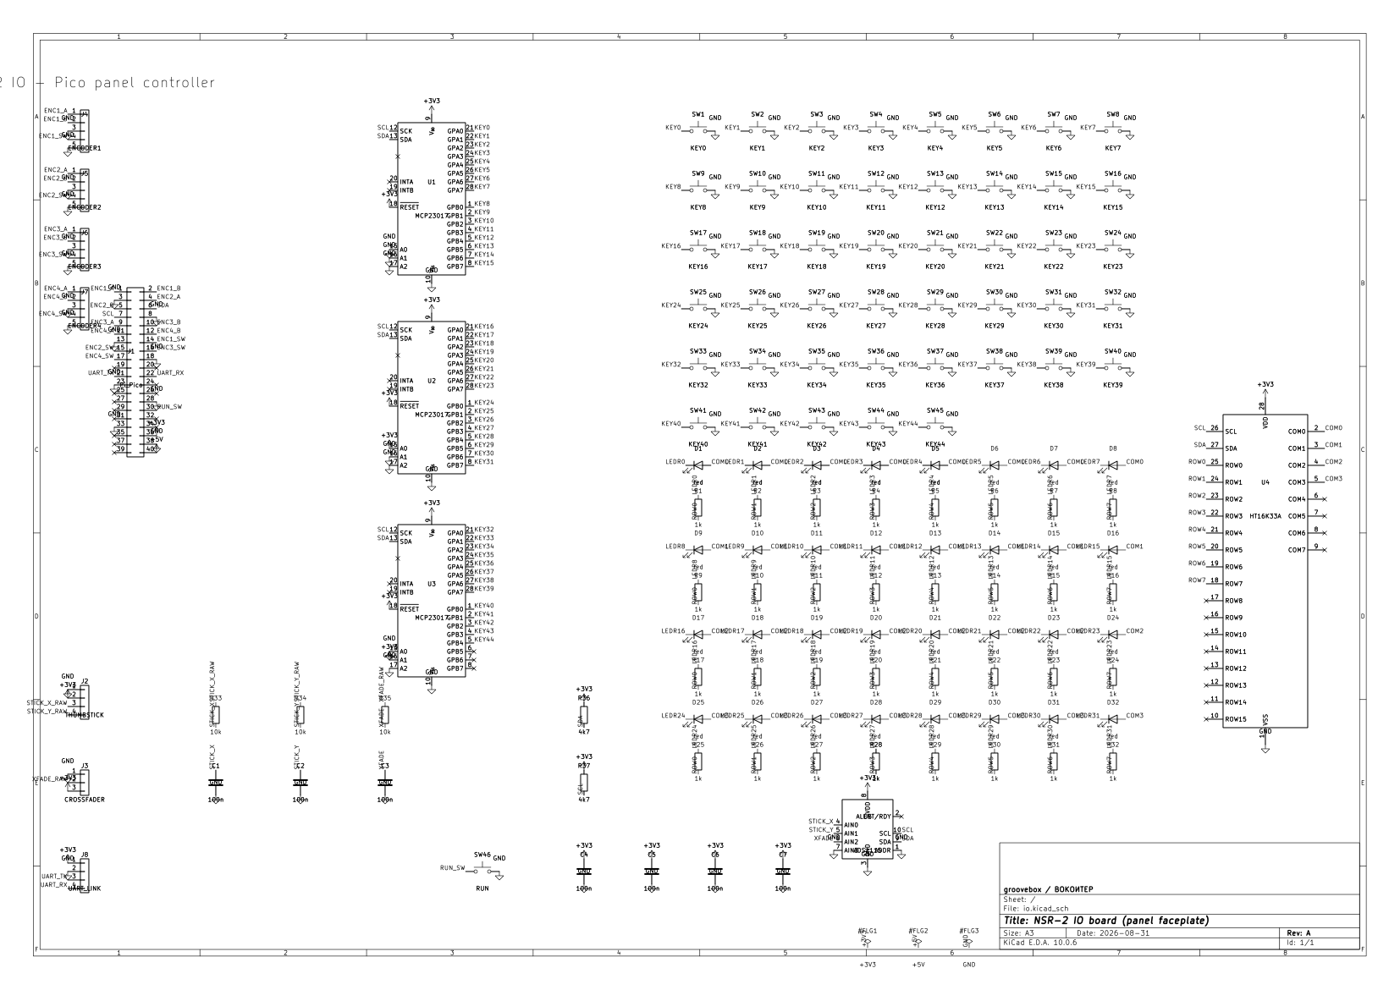
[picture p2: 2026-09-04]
nsr2/hardware/io/io_sch.png

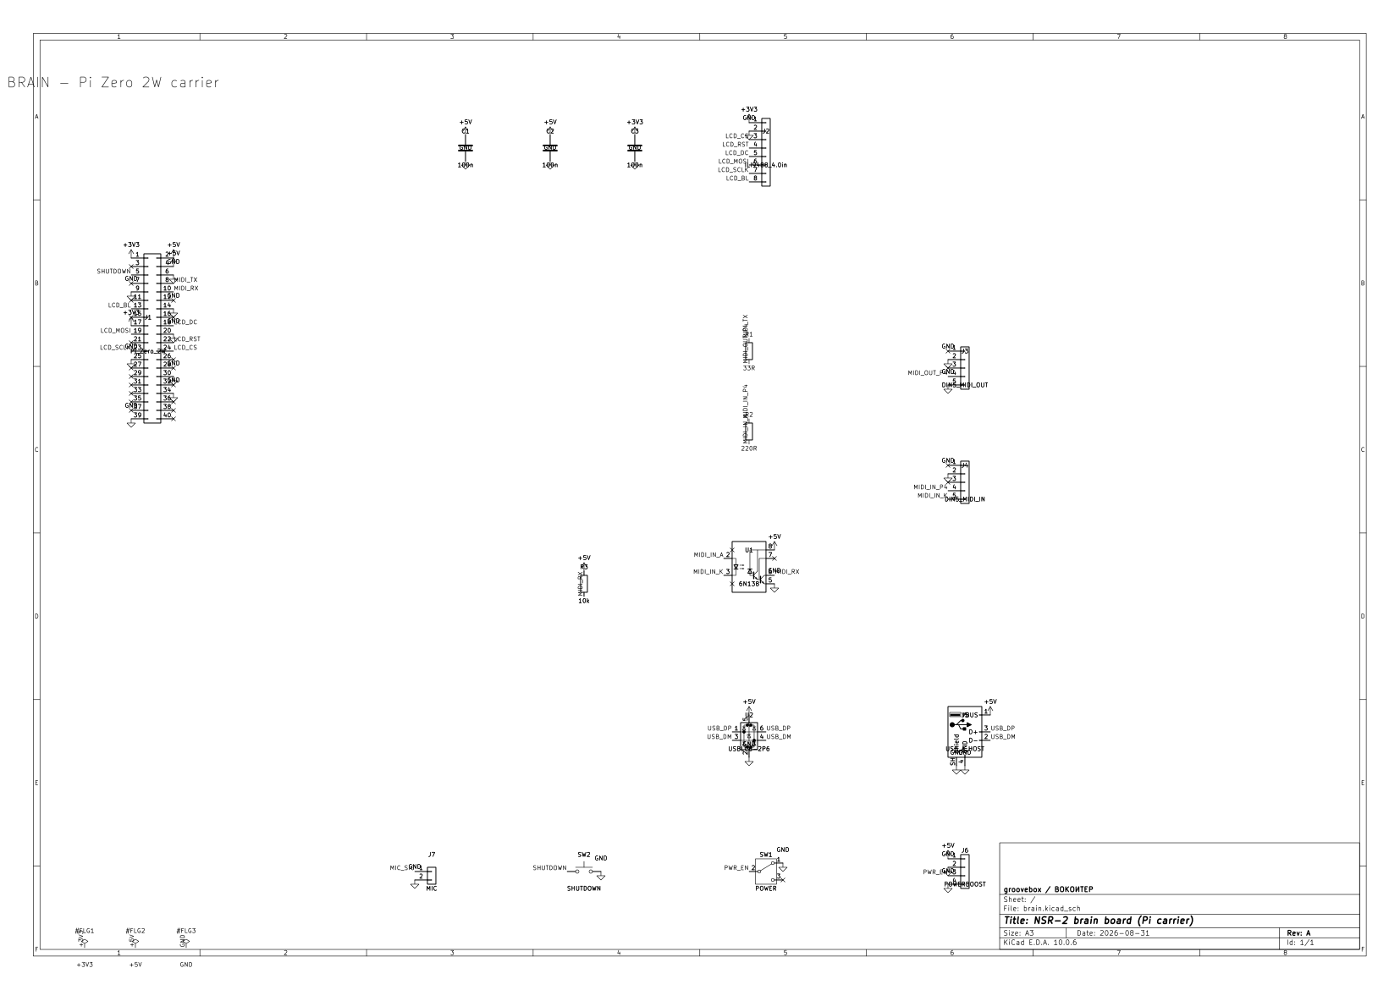
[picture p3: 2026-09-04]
nsr2/hardware/brain/brain_sch.png

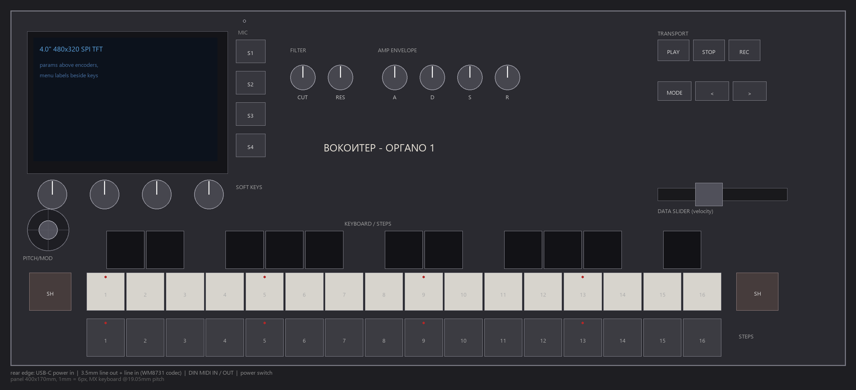
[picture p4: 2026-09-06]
docs/panel_mockup.png

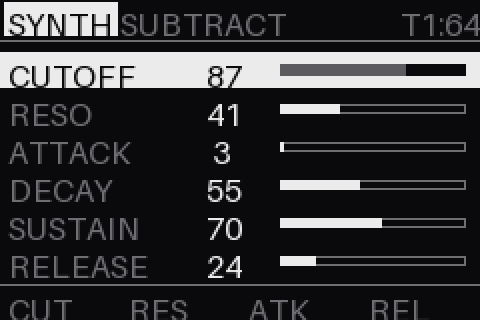
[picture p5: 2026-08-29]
docs/ui_mockup.png

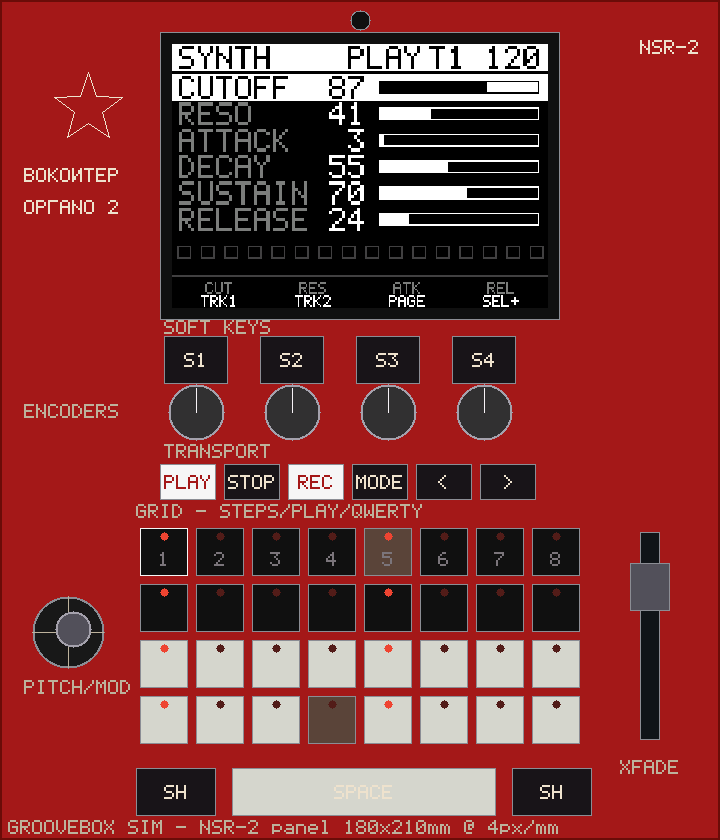
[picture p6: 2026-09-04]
docs/panel_sim_nsr2.png

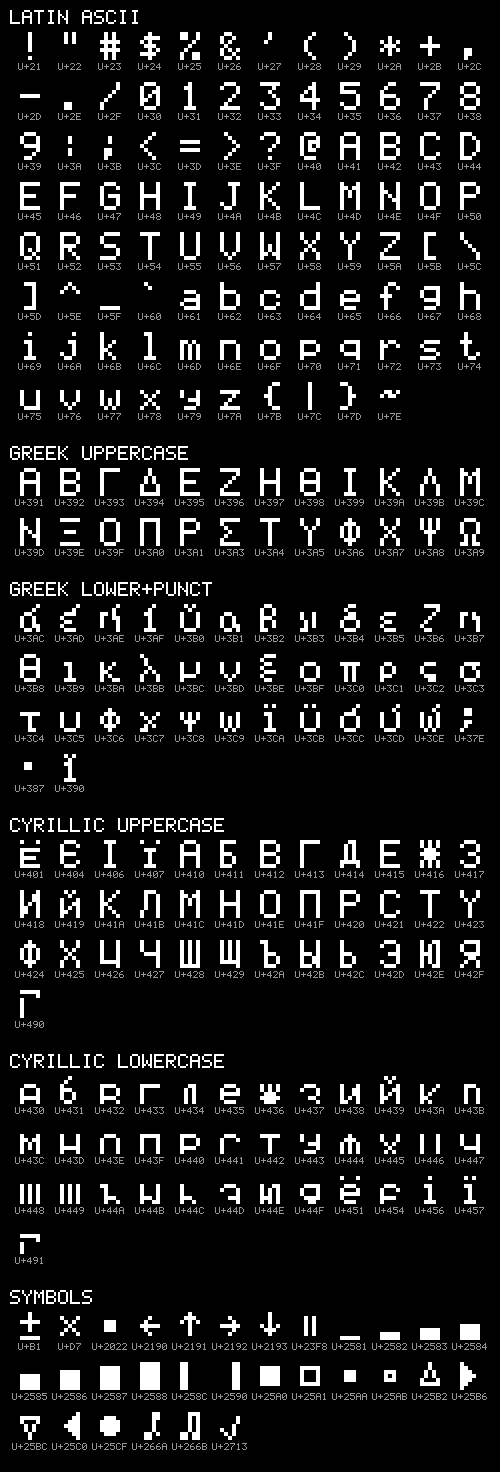
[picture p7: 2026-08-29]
docs/fontchart.png

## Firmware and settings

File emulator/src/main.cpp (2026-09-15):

// groovebox_sim — PC emulator for the groovebox control surface.
//
// Boots the yawn audio engine headlessly (PortAudio default output),
// a SubtractiveSynth on track 0 and a DrumRack on track 1, maps the
// simulated 39-key panel (key indices per docs/panel-protocol.md) to
// engine MIDI commands, and renders Elektron-style UI pages to the
// 240x160 framebuffer shown in an SDL3 window. Engine boot, sequencer
// triggers and note events are logged to stdout so the behavior is
// verifiable without listening.
//
// Tracks: T1 = SubtractiveSynth (melodic), T2/T3/T4 = DrumRack lanes
// (kick 36 / hat 38 / clap 39), all pattern-driven by the 16-step
// sequencer while the transport runs.
//
// Usage: groovebox_sim [--smoke|--seqtest|--uitest]
//                      [--fontchart [out.png]] [--widgets [out.png]]
//   --smoke     unattended boot + notes on both engine tracks + one
//               frame dump per page, clean shutdown.
//   --seqtest   unattended sequencer test: programs steps, plays at
//               120 BPM, changes BPM mid-play, mutes T3, records a
//               note, asserts trigger counts, dumps SEQ frames.
//   --uitest    unattended interaction test: hold-step pitch editing,
//               TRK+/TRK- wrap, shift-mute — all through the HAL event
//               path. Asserts fired notes per step.
//   --fontchart / --widgets  PNG review renderers, no engine.

#include "hal.h"
#ifdef GB_PI_BACKEND
#include "PiBackend.h" // headless Pi: fbdev display + RtMidi panel
#else
#include "SimBackend.h"
#endif
#include "ui.h"
#include "fontchart.h"
#include "widgetshowcase.h"
#include "pattern.h"
#include "PanelView.h"
#include "PanelViewNSR2.h" // was transitive via SimBackend.h
#include "capture.h"
#include "sampleio.h"

#include "stb_image_write.h" // implementation TU: fontchart.cpp
#ifndef GB_PI_BACKEND
#include <SDL3/SDL.h>        // --panelprobe injects synthetic mouse events
#endif

#include "audio/AudioEngine.h"
#include "audio/OfflineRenderer.h"
#include "util/Factory.h"
#include "util/MessageQueue.h"
#include "midi/MidiTypes.h"
#include "instruments/DrumRack.h"
#include "instruments/DrumSynth.h"
#include "instruments/DrumSlop.h"
#include "instruments/SubtractiveSynth.h"

#include <nlohmann/json.hpp>

#ifdef _WIN32
#ifndef NOMINMAX
#define NOMINMAX
#endif
#ifndef WIN32_LEAN_AND_MEAN
#define WIN32_LEAN_AND_MEAN
#endif
#include <windows.h>
#include <dbghelp.h>
#pragma comment(lib, "dbghelp.lib")
#endif

#include <chrono>
#include <cmath>
#include <cstdio>
#include <cstdlib>
#include <cstring>
#include <filesystem>
#include <memory>
#include <thread>
#include <variant>
#include <vector>

// Backend selection (see emulator/CMakeLists.txt GB_PI_BACKEND): the
// SDL3 sim on desktop, the headless fbdev+RtMidi backend on the Pi.
// Both implement the gb::Hal interface from hal.h.
#ifdef GB_PI_BACKEND
using HalBackend = gb::PiBackend;
#else
using HalBackend = gb::SimBackend;
#endif

namespace {

const char* noteName(int note, char* buf, size_t n) {
    static const char* kNames[12] = {"C", "C#", "D", "D#", "E", "F",
                                     "F#", "G", "G#", "A", "A#", "B"};
    std::snprintf(buf, n, "%s%d", kNames[note % 12], note / 12 - 1);
    return buf;
}

// Synthesized drum one-shots (M2d: one pad per per-track DrumRack —
// T2 kick@36, T3 hat@38, T4 clap@39).
std::vector<float> makeDrumSample(int kind, double sr) {
    std::vector<float> buf;
    uint32_t rng = 22222 + uint32_t(kind) * 7777;
    auto noise = [&rng] {
        rng = rng * 1664525u + 1013904223u;
        return int(rng >> 16) / 32768.0 - 1.0;
    };
    int frames = 0;
    switch (kind) {
    case 0: frames = int(sr * 0.30); break;  // kick
    case 1: frames = int(sr * 0.06); break;  // hat
    case 2: frames = int(sr * 0.25); break;  // clap
    default: frames = int(sr * 0.18); break; // snare
    }
    buf.resize(size_t(frames) * 2);
    double phase = 0.0;
    for (int i = 0; i < frames; ++i) {
        const double t = i / sr;
        float s = 0.0f;
        if (kind == 0) {      // kick: swept decaying sine
            const double freq = 40.0 + 90.0 * std::exp(-t * 25.0);
            phase += 2.0 * 3.14159265358979 * freq / sr;
            s = float(std::sin(phase) * std::exp(-t * 11.0) * 0.9);
        } else if (kind == 1) // hat: short noise burst
            s = float(noise() * std::exp(-t * 90.0) * 0.4);
        else if (kind == 2) { // clap: three bursts + tail
            const double burst = std::fmod(t, 0.03) < 0.012 && t < 0.09
                                     ? 1.0 : std::exp(-(t - 0.09) * 30.0);
            s = float(noise() * burst * 0.5);
        } else {              // snare: 180 Hz body + noise top
            const double body = std::sin(2.0 * 3.14159265358979 * 180.0 * t) *
                                std::exp(-t * 25.0);
            s = float((body * 0.6 + noise() * std::exp(-t * 20.0) * 0.4) *
                      0.6);
        }
        buf[size_t(i) * 2] = buf[size_t(i) * 2 + 1] = s;
    }
    return buf;
}
} // namespace

class App : public gb::HalHandler {
public:
    void setPanelProfile(gb::PanelProfile p) {
        m_nsr2 = (p == gb::kPanelNSR2);
        m_winSize = m_nsr2 ? 8 : 16;
        if (m_nsr2) m_velSource = 1; // NSR-2 default: fixed 100
    }
    void setProfileSeconds(int s) { m_profileSecs = s; }
    void setProfileLoad(const std::string& l) { m_profileLoad = l; }
    void setProfileFx(const std::string& f) { m_profileFx = f; }

    // testMode: 0 = interactive, 1 = --smoke, 2 = --seqtest
    int run(int testMode) {
        m_testMode = testMode;
        m_hal.setPanelProfile(m_nsr2 ? gb::kPanelNSR2 : gb::kPanelNSR1);
        std::printf("groovebox_sim — yawn engine emulator%s\n",
                    testMode == 1 ? " (smoke test)"
                    : testMode == 2 ? " (sequencer test)"
                    : testMode == 3 ? " (UI interaction test)"
                    : testMode == 4 ? " (long-pattern test)"
                    : testMode == 5 ? " (panel mouse probe)"
                    : testMode == 6 ? " (parameter/FX test)"
                    : testMode == 7 ? " (sample/settings test)"
                    : testMode == 8 ? " (NSR-2 grid test)"
                    : testMode == 9 ? " (NSR-1 rev B test)"
                    : testMode == 10 ? " (macro encoder test)"
                    : testMode == 11 ? " (track/channel test)"
                    : testMode == 12 ? " (bounce/clip test)"
                    : testMode == 13 ? " (drum key-map test)"
                    : testMode == 14 ? " (last-played-pad edit test)" : "");

        if (!m_hal.init(*this)) return 1;

        // ── Boot the yawn engine (mirrors the real app's init) ──────
        m_engine = std::make_unique<yawn::audio::AudioEngine>();
        yawn::audio::AudioEngineConfig cfg; // 48 kHz, 256 frames, defaults
        // PortAudio's default can be paNoDevice on bare Linux when the
        // "default" PCM (dmix) fails to open (seen on Pi Zero 2W Lite with
        // only vc4-hdmi present). Fall back to the first output-capable
        // device — typically the codec or HDMI audio.
        if (yawn::audio::AudioEngine::defaultOutputDevice() < 0) {
            for (const auto& d : yawn::audio::AudioEngine::enumerateDevices()) {
                if (d.maxOutputChannels > 0) {
                    cfg.outputDevice = d.id;
                    std::printf("[engine] PA default missing — using device %d (%s)\n",
                                d.id, d.name.c_str());
                    break;
                }
            }
        }
        if (!m_engine->init(cfg)) {
            std::fprintf(stderr, "[engine] init FAILED\n");
            return 1;
        }
        std::printf("[engine] init ok: %.0f Hz, %d frames, out=%dch in=%dch\n",
                    cfg.sampleRate, cfg.framesPerBuffer,
                    cfg.outputChannels, cfg.inputChannels);
        if (!m_engine->start()) {
            std::fprintf(stderr, "[engine] start FAILED (no audio device?)\n");
            return 1;
        }
        std::printf("[engine] started on default output device\n");

        // M2d: one engine track per UI track. T1 = SubtractiveSynth;
        // T2/T3/T4 each a DrumRack with its synthesized one-shot.
        m_engine->setInstrument(0, yawn::createInstrument("subsynth"));
        m_engine->sendCommand(yawn::audio::SetTrackTypeMsg{0, 1}); // MIDI
        static const char* kDrumNames[3] = {"kick", "hat", "clap"};
        for (int t = 1; t < 4; ++t) {
            auto rack = yawn::createInstrument("drumrack");
            auto* r = dynamic_cast<yawn::instruments::DrumRack*>(
                rack.get());
            if (r) {
                auto smp = makeDrumSample(t - 1, m_engine->sampleRate());
                r->loadPad(gb::Pattern::kPadNote[t], smp.data(),
                           int(smp.size()) / 2, 2);
            }
            m_engine->setInstrument(t, std::move(rack));
            m_engine->sendCommand(yawn::audio::SetTrackTypeMsg{t, 1});
        }
        m_engine->sendCommand(yawn::audio::TransportSetBPMMsg{m_state.bpm});
        std::printf("[engine] tracks 0-3: T1=SubtractiveSynth, "
                    "T2=kick T3=hat T4=clap (one DrumRack each)\n");
        for (int t = 0; t < 4; ++t) rebuildDrumVoices(t);

        // Bind pot/encoder params by name and sync the panel to the
        // engine: pots start engaged at the panel's default positions
        // (real panels adopt physical state at boot; pickup re-arms on
        // track/page changes only). ADSR encoders are relative.
        for (int t = 0; t < 4; ++t) // -1 = factory ADSR default
            for (int i = 0; i < 4; ++i)
                m_macroParamByTrack[t][i] = -1;
        rebindParams();
        for (int i = 0; i < 2; ++i) {
            if (m_potParam[i] >= 0) {
                setNormParam(m_potParam[i], m_state.params[i].value / 127.0f);
                m_potEngaged[i] = true;
                m_potPrev[i] = m_state.params[i].value / 127.0f;
            }
        }
        for (int i = 0; i < 4; ++i)
            if (m_adsrParam[i] >= 0)
                setNormParam(m_adsrParam[i], m_state.params[2 + i].value / 127.0f);

        // FX chooser list: descriptor display names + "NONE".
        for (const auto& d : yawn::audioEffectDescriptors())
            m_fxItems.push_back(d.displayName);
        m_fxItems.push_back("NONE");
        for (const auto& d : yawn::instrumentDescriptors())
            m_instItems.push_back(d.displayName);
        m_instItems.push_back("KEEP");
        for (const auto& d : yawn::midiEffectDescriptors())
            m_mfxItems.push_back(d.displayName);
        m_mfxItems.push_back("NONE");
        m_state.chooserItems = m_fxItems.data();
        m_state.chooserCount = int(m_fxItems.size());

        // settings + browser (persisted settings load interactive-only)
        m_state.nsr2 = m_nsr2;
        m_state.textBuf = m_textBuf;
        if (testMode == 0) loadSettings();
        syncSettingsUi();
        refreshBrowser();

        // Static widget geometry (SEQ page: 4 tracks x 16 steps + lane).
        m_state.seq.x = 24; m_state.seq.y = 32;
        m_state.seq.rows = gb::Pattern::kTracks; m_state.seq.rowH = 16;
        m_state.lane.x = 24; m_state.lane.y = 104;
        setPage(testMode == 2 ? 1 : 0);

        // --profile N: heavy-load harness runs INSTEAD of the
        // interactive/test loop, then falls through to shutdown.
        if (m_profileSecs > 0) {
            const int rc = runProfile(m_profileSecs);
            std::printf("[engine] stopping...\n");
            m_engine->stop();
            m_engine->shutdown();
            m_hal.shutdown();
            std::printf("[engine] shutdown complete\n");
            std::fflush(stdout);
            return rc;
        }

        // ── Main loop ───────────────────────────────────────────────
        std::printf("[app] running — %s\n",
                    testMode ? "test driver active" : "ESC quits");
        std::fflush(stdout);
        // Boot splash: interactive mode only (test drivers skip it so
        // timings stay exact).
        m_splash = (testMode == 0);
        m_splashStart = std::chrono::steady_clock::now();
        const auto t0 = std::chrono::steady_clock::now();
        auto lastBeat = t0;
        while (m_running) {
            m_hal.poll();

            m_engine->pollRetirements();
            yawn::audio::AudioEvent ev;
            while (m_engine->pollEvent(ev)) {
                // Live mixer levels: track 0-3 strips + master.
                if (auto* mu = std::get_if<yawn::audio::MeterUpdate>(&ev)) {
                    const float p = mu->peakL > mu->peakR ? mu->peakL
                                                          : mu->peakR;
                    const int slot = mu->trackIndex == -1 ? 4 : mu->trackIndex;
                    if (slot >= 0 && slot < 5) {
                        if (p > m_state.mixer.level[slot])
                            m_state.mixer.level[slot] = p;
                        if (p > m_state.mixer.peak[slot])
                            m_state.mixer.peak[slot] = p;
                    }
                }
            }
            // Meter decay (levels fast, peak markers slow).
            for (int i = 0; i < 5; ++i) {
                m_state.mixer.level[i] *= 0.92f;
                m_state.mixer.peak[i] *= 0.995f;
                if (m_state.mixer.peak[i] < m_state.mixer.level[i])
                    m_state.mixer.peak[i] = m_state.mixer.level[i];
            }

            updateSequencer();

            // Transport → UI clock + playing flag + REC indicator.
            const auto& tr = m_engine->transport();
            m_state.playing = tr.isPlaying();
            m_state.recording = m_recArmed && tr.isPlaying();
            const double beats = tr.positionInBeats();
            const double safeBeats = beats < 0.0 ? 0.0 : beats;
            m_state.clockBar   = int(safeBeats / 4.0) + 1;
            m_state.clockBeat  = int(safeBeats) % 4 + 1;
            m_state.clockStep  = int(safeBeats * 4.0) % 16 + 1;
            m_state.clockPhase = float(safeBeats - std::floor(safeBeats));

            syncPatternToUi();
            syncParamsToUi();
            pollSample();
            if (m_state.toastActive &&
                std::chrono::steady_clock::now() >= m_toastUntil)
                m_state.toastActive = false;
            macroTimeout(); // 3 s macro-assign timeout
            if (m_testMode) testStep(t0); // after state updates

            if (m_splash) {
                m_ui.renderSplash(m_fb);
                if (std::chrono::steady_clock::now() - m_splashStart >=
                    std::chrono::milliseconds(1800)) {
                    m_splash = false;
                    setPage(1); // auto-advance to SEQ after the splash
                    std::printf("[ui] splash done -> SEQ page\n");
                }
            } else {
                m_ui.render(m_state, m_fb);
            }
            m_hal.presentFrame(m_fb);

            const auto now = std::chrono::steady_clock::now();
            if (now - lastBeat >= std::chrono::seconds(2)) {
                lastBeat = now;
                std::printf("[engine] alive: cpu=%.1f%% running=%d\n",
                            m_engine->cpuLoad() * 100.0,
                            int(m_engine->isRunning()));
                std::fflush(stdout);
            }
            std::this_thread::sleep_for(std::chrono::milliseconds(8));
        }

        // ── Shutdown ────────────────────────────────────────────────
        std::printf("[engine] stopping...\n");
        m_engine->stop();
        m_engine->shutdown();
        m_hal.shutdown();
        std::printf("[engine] shutdown complete\n");
        std::fflush(stdout);
        if (m_testMode == 2) return seqtestVerdict();
        if (m_testMode == 3) return uitestVerdict();
        if (m_testMode == 4) return longtestVerdict();
        if (m_testMode == 5) return probeVerdict();
        if (m_testMode == 6) return paramtestVerdict();
        if (m_testMode == 7) return sampletestVerdict();
        if (m_testMode == 8) return nsr2testVerdict();
        if (m_testMode == 9) return revbtestVerdict();
        if (m_testMode == 10) return macrotestVerdict();
        if (m_testMode == 11) return tracktestVerdict();
        if (m_testMode == 12) return bouncetestVerdict();
        if (m_testMode == 13) return drumtestVerdict();
        if (m_testMode == 14) return padtestVerdict();
        return 0;
    }
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
int main(int argc, char** argv) {
    std::setvbuf(stdout, nullptr, _IONBF, 0); // crash-safe logging
#ifdef _WIN32
    // Dev crash handler: print exception + symbolicated stack.
    SetUnhandledExceptionFilter([](EXCEPTION_POINTERS* ep) -> LONG {
        std::printf("\n!!! CRASH 0x%08X at %p (data %s %p)\n",
                    ep->ExceptionRecord->ExceptionCode,
                    ep->ExceptionRecord->ExceptionAddress,
                    ep->ExceptionRecord->ExceptionInformation[0] ? "write"
                                                                 : "read",
                    (void*)ep->ExceptionRecord->ExceptionInformation[1]);
        HANDLE proc = GetCurrentProcess();
        SymInitialize(proc, nullptr, TRUE);
        void* stack[32];
        const USHORT n = CaptureStackBackTrace(0, 32, stack, nullptr);
        auto* si = static_cast<SYMBOL_INFO*>(
            malloc(sizeof(SYMBOL_INFO) + 256));
        si->SizeOfStruct = sizeof(SYMBOL_INFO);
        si->MaxNameLen = 255;
        for (int i = 0; i < n; ++i)
            if (SymFromAddr(proc, DWORD64(stack[i]), nullptr, si))
                std::printf("  %s+0x%llx\n", si->Name,
                            DWORD64(stack[i]) - si->Address);
        free(si);
        std::fflush(stdout);
        return EXCEPTION_EXECUTE_HANDLER;
    });
#endif
    gb::PanelProfile panel = gb::kPanelNSR1;
    for (int i = 1; i < argc; ++i) {
        if (std::strncmp(argv[i], "--panel=", 8) == 0) {
            panel = std::strcmp(argv[i] + 8, "nsr2") == 0 ? gb::kPanelNSR2
                                                          : gb::kPanelNSR1;
        }
    }
    for (int i = 1; i < argc; ++i) {
        if (std::strcmp(argv[i], "--version") == 0) {
            std::printf("groovebox_sim %s\n", GB_VERSION_STRING);
            return 0;
        }
        if (std::strcmp(argv[i], "--devices") == 0) {
            std::printf("default out=%d in=%d\n",
                        yawn::audio::AudioEngine::defaultOutputDevice(),
                        yawn::audio::AudioEngine::defaultInputDevice());
            for (const auto& d : yawn::audio::AudioEngine::enumerateDevices())
                std::printf("  [%d] %s (%s) in=%d out=%d %.0fHz\n", d.id,
                            d.name.c_str(), d.hostApi.c_str(),
                            d.maxInputChannels, d.maxOutputChannels,
                            d.defaultSampleRate);
            return 0;
        }
        if (std::strcmp(argv[i], "--fontchart") == 0) {
            const char* out = (i + 1 < argc && argv[i + 1][0] != '-')
                                  ? argv[i + 1] : "fontchart.png";
            return gb::writeFontChartPng(out) ? 0 : 1;
        }
        if (std::strcmp(argv[i], "--widgets") == 0) {
            const char* out = (i + 1 < argc && argv[i + 1][0] != '-')
                                  ? argv[i + 1] : "widgets.png";
            return gb::writeWidgetShowcasePng(out) ? 0 : 1;
        }
        if (std::strcmp(argv[i], "--paneldump") == 0) {
            const char* out = (i + 1 < argc && argv[i + 1][0] != '-')
                                  ? argv[i + 1] : "panel.png";
            return writePanelDumpPng(out, panel) ? 0 : 1;
        }
        if (std::strcmp(argv[i], "--splashdump") == 0) {
            const char* out = (i + 1 < argc && argv[i + 1][0] != '-')
                                  ? argv[i + 1] : "bootsplash.png";
            return writeSplashDumpPng(out) ? 0 : 1;
        }
        if (std::strcmp(argv[i], "--themes") == 0) {
            const char* out = (i + 1 < argc && argv[i + 1][0] != '-')
                                  ? argv[i + 1] : "themes.png";
            return gb::writeThemesPng(out) ? 0 : 1;
        }
    }
    int testMode = 0;
    int profileSecs = 0;
    std::string profileLoad = "heavy";
    std::string profileFx = "reverb";
    for (int i = 1; i < argc; ++i) {
        if (std::strcmp(argv[i], "--smoke") == 0)      testMode = 1;
        if (std::strcmp(argv[i], "--seqtest") == 0)    testMode = 2;
        if (std::strcmp(argv[i], "--uitest") == 0)     testMode = 3;
        if (std::strcmp(argv[i], "--longtest") == 0)   testMode = 4;
        if (std::strcmp(argv[i], "--panelprobe") == 0) testMode = 5;
        if (std::strcmp(argv[i], "--paramtest") == 0)  testMode = 6;
        if (std::strcmp(argv[i], "--sampletest") == 0) testMode = 7;
        if (std::strcmp(argv[i], "--nsr2test") == 0)   testMode = 8;
        if (std::strcmp(argv[i], "--revbtest") == 0)   testMode = 9;
        if (std::strcmp(argv[i], "--macrotest") == 0)  testMode = 10;
        if (std::strcmp(argv[i], "--tracktest") == 0)  testMode = 11;
        if (std::strcmp(argv[i], "--bouncetest") == 0) testMode = 12;
        if (std::strcmp(argv[i], "--drumtest") == 0)   testMode = 13;
        if (std::strcmp(argv[i], "--padtest") == 0)    testMode = 14;
        if (std::strcmp(argv[i], "--profile") == 0 && i + 1 < argc)
            profileSecs = std::atoi(argv[i + 1]);
        if (std::strcmp(argv[i], "--load") == 0 && i + 1 < argc)
            profileLoad = argv[i + 1];
        if (std::strcmp(argv[i], "--fx") == 0 && i + 1 < argc)
            profileFx = argv[i + 1];
    }
    App app;
    app.setPanelProfile(panel);
    app.setProfileSeconds(profileSecs);
    app.setProfileLoad(profileLoad);
    app.setProfileFx(profileFx);
    return app.run(testMode);
}

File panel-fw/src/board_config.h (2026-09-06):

#pragma once

// Hardware-facing constants for the groovebox panel module (rev B2).
// Docs: docs/panel-protocol.md, docs/design.md, hardware/netlist-spec.md.
//
// Key architecture: ALL 55 panel keys are single-ended inputs on four
// MCP23017 I2C expanders (switch to GND, expander pull-ups). No matrix, no
// diodes. The HT16K33 drives the 32 LEDs only (16 step row + 16 white key).
// Rev B2: 8 encoders (quadrature on direct GPIO, pushes on expander spare
// pins), analog shrinks to 2x ADS1115 (2 pots + slider + joystick X/Y).

#include <stdint.h>

// ── I2C bus (4x MCP23017 keys, HT16K33 LEDs, 2x ADS1115 analog) ─────
#define PANEL_I2C            i2c0
#define PANEL_I2C_SDA_PIN    4
#define PANEL_I2C_SCL_PIN    5
#define PANEL_I2C_BAUD       400000

// Bounded I2C: every transaction uses a timeout so an absent or wedged chip
// (NACK / stuck bus) can never stall the superloop. ~30 us/byte at 400 kHz,
// so 2 ms is generous for the longest transfer (17-byte LED flush).
#define PANEL_I2C_TIMEOUT_US 2000

#define HT16K33_ADDR         0x70    // LED driver only (no key scan)

#define ADS_ADDR_CH0         0x48    // AIN0/1 = pots CUT/RES, AIN2 = slider,
                                     // AIN3 = joystick Y
#define ADS_ADDR_CH1         0x49    // AIN0 = joystick X (pitch bend)
#define ADS_CHIP_COUNT       2       // rev B2: 0x4A dropped

#define MCP_ADDR_WHITE       0x20    // GPA0-15: white keys 0..15
#define MCP_ADDR_BLACK       0x21    // pins 0-10: black keys 16..26,
                                     // pins 11/12: shifts 38/39,
                                     // pin 13: joystick SW (index 30),
                                     // pins 14/15: encoder pushes 1/2
#define MCP_ADDR_FN          0x22    // pins 0-9: function keys,
                                     // pins 10-15: encoder pushes 3-8
#define MCP_ADDR_STEP        0x23    // GPA0-15: step-row keys 40..55 (rev B)

#define KEY_CHIP_COUNT       4       // MCP23017 expanders on the bus
#define KEY_COUNT            56      // valid key indices 0..55 (55 keys +
                                     // joystick push on index 30)

// Key index per expander pin; 0xFF = unused (route PCB to match).
typedef struct {
    uint8_t addr;
    uint8_t map[16];
} key_chip_t;

static const key_chip_t KEY_CHIPS[KEY_CHIP_COUNT] = {
    { MCP_ADDR_WHITE,
      { 0,  1,  2,  3,  4,  5,  6,  7,          // white keys 1-16
        8,  9, 10, 11, 12, 13, 14, 15 } },
    { MCP_ADDR_BLACK,
      { 16, 17, 18, 19, 20, 21, 22, 23,         // black keys 1-11
        24, 25, 26,
        38, 39,                                  // SHIFT-L, SHIFT-R
        30,                                      // joystick SW (moved here in B2)
        0xFF, 0xFF } },                          // encoder pushes 1/2 (PUSH_MAP)
    { MCP_ADDR_FN,
      { 27, 28, 29, 31, 32, 33,                  // PLAY, STOP, REC, MODE, <, >
        34, 35, 36, 37,                          // S1-S4
        0xFF, 0xFF, 0xFF, 0xFF, 0xFF, 0xFF } },  // encoder pushes 3-8 (PUSH_MAP)
    { MCP_ADDR_STEP,
      { 40, 41, 42, 43, 44, 45, 46, 47,          // step row 1-16 (rev B)
        48, 49, 50, 51, 52, 53, 54, 55 } },
};

// Encoder push-buttons (rev B2): no longer direct GPIO — they ride the
// key-scan reads on spare expander pins. PUSH_MAP[c][pin] = encoder push
// index 0..7 (emitted as CC 32+index, 127 press / 0 release), 0xFF = not a
// push. Same debounce path as keys.
static const uint8_t PUSH_MAP[KEY_CHIP_COUNT][16] = {
    { 0xFF, 0xFF, 0xFF, 0xFF, 0xFF, 0xFF, 0xFF, 0xFF,      // 0x20 white: none
      0xFF, 0xFF, 0xFF, 0xFF, 0xFF, 0xFF, 0xFF, 0xFF },
    { 0xFF, 0xFF, 0xFF, 0xFF, 0xFF, 0xFF, 0xFF, 0xFF,      // 0x21 pins 14/15:
      0xFF, 0xFF, 0xFF, 0xFF, 0xFF, 0xFF,    0,    1 },    // pushes 1/2
    { 0xFF, 0xFF, 0xFF, 0xFF, 0xFF, 0xFF, 0xFF, 0xFF,      // 0x22 pins 10-15:
      0xFF, 0xFF,    2,    3,    4,    5,    6,    7 },    // pushes 3-8
    { 0xFF, 0xFF, 0xFF, 0xFF, 0xFF, 0xFF, 0xFF, 0xFF,      // 0x23 step: none
      0xFF, 0xFF, 0xFF, 0xFF, 0xFF, 0xFF, 0xFF, 0xFF },
};

// ── Encoders (rev B2: 8 total) ──────────────────────────────────────
// Quadrature A/B on 16 direct GPIO; push-buttons live on MCP23017 spare
// pins (see PUSH_MAP above). Pin map:
//   enc 1-4 (pageable):  A/B = GP0/1, GP2/3, GP6/7, GP8/9   (unchanged)
//   enc 5-8 (ADSR, B2):  A/B = GP14/15, GP18/19, GP20/21, GP22/26
// Avoided: GP4/5 (I2C), GP16/17 (UART link header), GP25 (heartbeat LED).
#define ENC_NUM              8
static const uint8_t ENC_A_PIN[ENC_NUM]  = { 0, 2, 6, 8, 14, 18, 20, 22 };
static const uint8_t ENC_B_PIN[ENC_NUM]  = { 1, 3, 7, 9, 15, 19, 21, 26 };

// ── HT16K33 key data RAM read ───────────────────────────────────────
// Unused (no key scan); kept for reference.
#define HT16K33_KEY_BYTES    6
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

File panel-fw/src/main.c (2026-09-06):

// groovebox-panel firmware entry point (rev B2).
// Superloop + 1 ms tick: USB MIDI via TinyUSB, 4x MCP23017 key scan (55 keys
// + 8 encoder pushes), 2x ADS1115 analog polling, 8 quadrature encoders,
// HT16K33 LED output (32 LEDs), GRV config service. Watchdog (4 s) kicked
// every loop iteration.
// USB comes up FIRST and independently of the peripherals: every I2C chip is
// probed with a bounded timeout and skipped when absent, so the device
// enumerates with any subset of the panel attached (bare-board bring-up).
// GP25 heartbeat: slow blink = all peripherals online, fast blink = degraded.

#include "pico/stdlib.h"
#include "hardware/i2c.h"
#include "hardware/gpio.h"
#include "hardware/watchdog.h"
#include "tusb.h"

#include "ads1115.h"
#include "board_config.h"
#include "config.h"
#include "encoder.h"
#include "keys.h"
#include "leds.h"
#include "midi.h"

int main(void) {
    tusb_init();

    config_init();

    i2c_init(PANEL_I2C, PANEL_I2C_BAUD);
    gpio_set_function(PANEL_I2C_SDA_PIN, GPIO_FUNC_I2C);
    gpio_set_function(PANEL_I2C_SCL_PIN, GPIO_FUNC_I2C);
    gpio_pull_up(PANEL_I2C_SDA_PIN);
    gpio_pull_up(PANEL_I2C_SCL_PIN);

    leds_init();
    keys_init();
    ads_init();
    encoder_init();

    gpio_init(PICO_DEFAULT_LED_PIN);
    gpio_set_dir(PICO_DEFAULT_LED_PIN, GPIO_OUT);

    // All init I2C is bounded (PANEL_I2C_TIMEOUT_US), so this point is
    // reached in milliseconds even with every peripheral absent.
    watchdog_enable(4000, true);    // 4 s, paused while a debugger is attached

    unsigned hb_ms = 0;
    bool hb = false;
    absolute_time_t next_tick = make_timeout_time_ms(1);
    while (true) {
        watchdog_update();
        tud_task();
        midi_task();
        if (time_reached(next_tick)) {
            next_tick = delayed_by_us(next_tick, 1000);
            keys_tick();
            ads_tick();
            encoder_tick();
            leds_tick();
            config_service();
            const bool degraded =
                keys_any_offline() || !leds_online() || ads_any_offline();
            if (++hb_ms >= (degraded ? 100u : 500u)) {
                hb_ms = 0;
                hb = !hb;
                gpio_put(PICO_DEFAULT_LED_PIN, hb);
            }
        }
    }
    return 0;
}

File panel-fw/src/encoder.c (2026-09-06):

#include "encoder.h"
#include "board_config.h"
#include "midi.h"
#include "hardware/gpio.h"
#include "hardware/sync.h"
#include "pico/stdlib.h"

// Quadrature: full 4-state table on A/B edges (IRQ), detents emitted from
// the 1 ms tick so MIDI stays out of IRQ context. Push-buttons are NOT here:
// rev B2 moves them to spare MCP23017 inputs (see PUSH_MAP, keys.c).

static const int8_t qdec[16] = {  0, -1,  1,  0,
                                  1,  0,  0, -1,
                                 -1,  0,  0,  1,
                                  0,  1, -1,  0 };

static void irq_cb(uint gpio, uint32_t events);

static int8_t delta[ENC_NUM];
static uint8_t prev[ENC_NUM];

void encoder_init(void) {
    for (unsigned e = 0; e < ENC_NUM; e++) {
        gpio_init(ENC_A_PIN[e]); gpio_pull_up(ENC_A_PIN[e]);
        gpio_init(ENC_B_PIN[e]); gpio_pull_up(ENC_B_PIN[e]);
        prev[e] = (uint8_t)((gpio_get(ENC_A_PIN[e]) << 1) | gpio_get(ENC_B_PIN[e]));
        gpio_set_irq_enabled_with_callback(
            ENC_A_PIN[e], GPIO_IRQ_EDGE_RISE | GPIO_IRQ_EDGE_FALL, true, &irq_cb);
        gpio_set_irq_enabled(
            ENC_B_PIN[e], GPIO_IRQ_EDGE_RISE | GPIO_IRQ_EDGE_FALL, true);
    }
}

static void irq_cb(uint gpio, uint32_t events) {
    (void)events;
    for (unsigned e = 0; e < ENC_NUM; e++) {
        uint8_t a = ENC_A_PIN[e], b = ENC_B_PIN[e];
        if (gpio != a && gpio != b) continue;
        const uint8_t cur = (uint8_t)((gpio_get(a) << 1) | gpio_get(b));
        delta[e] += qdec[(prev[e] << 2) | cur];
        prev[e] = cur;
        return;
    }
}

void encoder_tick(void) {
    for (unsigned e = 0; e < ENC_NUM; e++) {
        // Read-and-clear under a critical section: the GPIO IRQ accumulates
        // into delta[e], and a plain read/decrement loop here could lose
        // transitions that land between the test and the update.
        const uint32_t irq = save_and_disable_interrupts();
        int d = delta[e];
        delta[e] = 0;
        restore_interrupts(irq);
        while (d > 0)  { midi_send_cc(0, (uint8_t)(16 + e), 65); d--; }
        while (d < 0)  { midi_send_cc(0, (uint8_t)(16 + e), 63); d++; }
    }
}

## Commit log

2026-08-29 Initial import: design docs, SDL3 panel emulator, Pi OS image config
    - docs/: hardware/software design, panel protocol, mockups and renders
    - emulator/: groovebox_sim, SDL3 HAL emulator booting the yawn engine headlessly (synth + drum rack, 4x256-step sequencer, panel view, test drivers)
    - tools/: Python mockup/render utilities
    - os-image/: Raspberry Pi OS Lite first-boot customization (large .img.xz images kept out of the repo)
    - yawn: pinned as a submodule (shallow clone at 74c09fd)
2026-08-29 panel-fw: Pico USB-MIDI panel firmware, protocol v1
    - 39-key HT16K33 matrix scan (3-sample debounce) as Note On/Off ch1
    - 3x ADS1115 round-robin analog: pots CC20-25, slider CC26, joystick CC1/bend
    - 4 quadrature encoders (relative CC16-19) + debounced pushes (CC32-35)
    - 16 step LEDs driven from ch2 notes; periodic re-assert
    - GRV SysEx 0x7D config: velocity source routing (slider/pots/joyY/fixed/host
    register CC27 ch2), QUERY/REPLY capability handshake, configurable flash
    persistence (volatile default, save-on-change with 1s coalescing)
    - build.ps1 + user-scoped toolchain layout; builds clean with pico-sdk 1.5.1
    [ads1115.c, board_config.h, encoder.c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]
2026-08-29 panel-fw: uniform key input on 3x MCP23017 expanders
    All 39 keys single-ended on I2C expanders (16 whites / 11 blacks+2 shifts /
    10 function keys + joystick SW). matrix.c and fnkeys.c replaced by keys.c;
    HT16K33 demoted to LED driver only; 13 Pico GPIOs freed for rev B.
    [board_config.h, keys.c, main.c]
2026-08-29 hardware: KiCad project skeletons + netlist spec (rev A)
    - control/keyboard board outlines with mounting holes
    - netlist-spec.md: full connector pinouts, I2C map, ADS1115 channel map,
    MCP23017 key maps, BOM split, bring-up checklist
    - design.md: document expander key-scan deviation
    [control.kicad_pcb, control.kicad_sch, keyboard.kicad_pcb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]
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2026-09-01 nsr2: compact panel variant - design docs, schematics, footprints, enclosure
    - docs/nsr2-design.md: NSR-2 concept, locked decisions, hardware delta, firmware plan
    - nsr2/netlist-spec.md: two-board hardware contract (brain 100x80 + io faceplate 180x210), 3x MCP23017 key expanders, HT16K33A LED driver, 1x ADS1115, protocol notes (feature bit 3 = 32-grid layout)
    - nsr2/README.md: collaboration contract (generated schematics are code; KiCad GUI is review-only until freeze), known-benign ERC warnings, red-flag list
    - nsr2/tools/gen_schematics.py: generates both .kicad_sch from the spec (labels+power symbols, no wires); 0 ERC errors on both boards
    - custom HT16K33A symbol from the Holtek Rev 1.11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
    [brain.kicad_pcb, brain.kicad_sch, io.kicad_pcb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]
2026-09-04 M2 complete: full instrument in emulator + panel-fw fixes
    Emulator (M2a/M2b/M2c):
    - Live 4-track step sequencer (1-256 steps, per-step velocity/accent/pitch/gate)
    - Play mode: 2-octave chromatic keyboard, pitch bend/mod, REC quantization
    - Virtual front panel: red ВОКОИТЕР - ОРГАНО 1 badge, 4.0in layout, mouse-interactive
    - Themes (mono/red/green) + ПОЕХАЛИ boot splash
    - Pots with pickup + encoder param pages (strict one-param-one-control), FX page, toasts
    - SAMPLE page (engine capture, trim/normalize/assign to pads), LOAD browser, SETTINGS, dialogs
    - Test modes: smoke/uitest/seqtest/longtest/paramtest/panelprobe/widgets/fontchart/themes
    panel-fw: ADS1115 16-bit scaling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
    [SimBackend.cpp, ads1115.c, encoder.c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]
2026-09-04 emulator: NSR-2 panel profile, auto-sizing toasts, git-tag versioning
    - --panel=<nsr1|nsr2> profile: NSR-2 portrait faceplate (180x210, star badge),
    4x8 LED grid with mouse hit-testing, crossfader, thumbstick
    - NSR-2 semantics: MODE cycles PLAY/SEQ/TEXT; grid = 4 tracks x 8-step window;
    isomorphic play mode with MAJOR/MINOR/CHROMATIC scale lock (SETTINGS);
    QWERTY text-entry mode feeding EditBox; 32 grid LEDs
    - docs/panel-protocol.md: NSR-2 section (notes 36-80, 32 LEDs, feature bit 3)
    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
2026-09-06 rev B/B2: dedicated step row, 2 pots + 8 macro encoders, panel-fw fixes
    Design (docs):
    - NSR-1 rev B: 16-key step row under the piano (55 keys, notes 36-91,
    32 LEDs), piano always playable, hold-step+piano = p-lock pitch,
    shift+step = accent/select/mute, MODE = scale lock
    - rev B2: 2 pots (CUT/RES) + 8 encoders; encoders 5-8 are macro encoders
    (ADSR default, shift+push to assign); encoder pushes on expander pins
    - protocol: NSR-2 section, velocity-source codes updated for 2 pots
    Emulator:
    - Rev B panel view (400x170, step row) + rev B2 controls
    - Macro assign flow with per-track persistence; ownership rule three-way
    (pots/macros/pages), toasts, --revbtest/--macrotest
    panel-fw:
    - Ti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
    [PanelView.cpp, PanelView.h, SimBackend.cpp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]
2026-09-07 M2d + M3: channel types/pages, record/bounce, Pi backend, arm64 cross-build
    M2d (channel architecture):
    - One engine track per UI track (T1-T4 -> engine 0-3), engine-level mutes
    - New pages: TRACK (MIDI/AUDIO type, vol/pan/input), INST (instrument
    picker + full param rebind), MFX (MIDI effect slot + params + bypass),
    FX gains 2nd insert slot
    - AUDIO tracks: record input to looping clip (pending-clip finalize works
    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
2026-09-07 ui: drum playability — key→voice mapping + last-pad editing
    - INST chooser overlay renders on INST page (was invisible; S1 confirmed blind)
    - Drum play mode: keys map to drum voices with wraparound (every key sounds);
    DrumSynth 8 voices, DrumRack loaded pads, DrumSlop slice pads
    - Drum sequencer: steps default to kick, hold-step p-locks voice (toast with
    name), encoder cycles voices, REC records voices
    - Last-played-pad editing: INST page follows the played pad (PAD/PAD2/KIT
    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
2026-09-15 M3 on hardware + plate reverb: Zero 2W bring-up, profiling, optimizations
    yawn submodule -> 54b1563 (plate reverb + Freeverb fixes on master)
    Pi Zero 2W bring-up (real hardware):
    - tools/pish.py SSH/SFTP helper; Pi on the network as groovebox.local
    - PortAudio device fallback (no default device on Lite with HDMI-only audio)
    - --devices flag; --load heavy|real|lean profile variants; --fx <id> selector
    - cortex-a53 tuning in the aarch64 toolchain (NEON is mandatory on AArch64)
    - Pi hardening: bluetooth + serial-getty disabled, performance governor,
    snd-dummy persistent; .asoundrc
    - Profiling gate results on real hardware: lean 36-43% clean,
    real 55-66% clean, heavy ~101% xruns (2x freever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
    [main.cpp]
2026-11-02 hardware: generate rev B2 NSR-1 schematics
    Add the rev B2 netlist contract, generated control/keyboard schematics, MX hot-swap footprint, netlist export, KiCad checks, firmware pin-map updates, and rev B2 board outlines. EMD imports and validates both board netlists.
2026-11-02 hardware: place the NSR-1 control board
    Grow the control board to 120 x 90 mm for connector clearance, place all 50 components with schematic nets assigned, and add the placement script. DRC is clean apart from the expected unrouted ratsnest.
2026-11-02 hardware: place the NSR-1 keyboard board
    Place all 45 MX switches on the 19.05 mm piano/step grid, the 32 in-switch LEDs and resistors, three key expanders, HT16K33, link, and decoupling. Keyboard DRC is clean apart from the expected unrout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
2026-11-02 hardware: route the NSR-1 control board
    Auto-route the placed control board with Freerouting using 0.15 mm minimum track width and clearance. The routed board has 0 DRC violations and 0 unconnected items.
2026-11-02 hardware: route the NSR-1 keyboard board
    Auto-route the keyboard matrix, LED, and expander nets with Freerouting. Both NSR-1 boards now have 0 DRC violations and 0 unconnected items.
2026-11-02 hardware: add NSR-1 fabrication export
    Add a repeatable KiCad 10 export for Gerbers, drill files, position data, BOM, STEP, and board statistics, with zip archives for both NSR-1 boards.
2026-11-02 hardware: add NSR-1 mounting holes and EMD PCB import
    Replace Edge.Cuts mounting circles with M3 mounting-hole footprints on both boards and extend the EMD integration check to import the routed PCBs and validate their mechanical ports.
2026-11-02 hardware: add ground pours and NSR-1 fit/package checks
    Fill a B.Cu ground pour on both routed boards, define the 400 x 170 mm panel/under-board stack-up, verify the mechanical envelope, and extend the EMD integration check to produce and verify board pac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
2026-11-02 hardware: compact the keyboard board for panel fit
    Shrink the keyboard PCB to 356 x 80 mm, move the LED resistors into the switch gaps and service parts into the inter-row space, reroute, refill the ground pour, and update the panel/enclosure fit contract. The keyboard uses 0.15 mm tracks with 0.12 mm minimum clearance.
2026-11-02 hardware: add printable tray and power review
    Add a FreeCAD-generated 406 x 176 x 35 mm NSR-1 tray with board posts, plus the rev B2 power/thermal review.
2026-11-02 hardware: add the NSR-1 cutout faceplate
    Generate the 400 x 170 mm faceplate with the rev B2 key, screen, encoder, pot, transport, slider, joystick, and mic cutouts, and align the keyboard/fit/combined-project origins.
2026-11-02 docs: reference the ElectroMechanicalDesigner integration
    Document the NSR-1 EMD import, combined project, package verification, and fabrication flow, and update the hardware/repo maps.
2026-11-02 docs: add Blender NSR-1 exploded and assembled renders
    Generate the exploded/assembled Blender scene from the rev B2 tray, faceplate, and board layout, with labeled and unlabeled renders and an EMD validation caption.
2026-11-02 docs: correct the NSR-1 render orientation and panel spacing
    Mirror the panel assembly to match the reference mockup, center the assembled view, move the encoder row clear of the joystick, and add key/panel labels, encoder marks, LEDs, and screen UI to the Blender render.
2026-11-02 docs: fix NSR-1 render LEDs and label positions
    Place the step LEDs on the step-key row, align the panel labels with their controls, and regenerate the exploded/assembled renders.
2026-11-02 docs: add the NSR-1 15-second detail animation
    Render a 30 fps exploded-to-assembled animation with hero, screen/encoder, and keyboard close-ups, plus the editable Blender scene and camera keyframes.
2026-11-02 docs: remove perspective distortion from NSR-1 renders
    Use a straight top-down orthographic camera for the exploded, assembled, and detail shots, and re-render the 15-second animation.
2026-11-02 docs: add NSR-1 PCB top and bottom renders
    Add 3D top and bottom views of the routed control and keyboard boards.
2026-11-02 hardware: start the NSR-1 platform with a Pi carrier
    Adopt a separate-carrier-per-SBC strategy, make NSR-1 the active target, add the Pi Zero 2W brain carrier schematic and netlist, define the power/battery board, and specify the enclosure adapter/batt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
2026-11-02 hardware: correct Pico and Pi Zero module footprints
    Replace the generic 2x20 Pico socket with the 17.78 mm-row Pico module footprint, add the Pi Zero socketed module profile and mounting holes, re-route the affected boards, add header/connector silkscreen labels, and refresh the PCB renders.
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
